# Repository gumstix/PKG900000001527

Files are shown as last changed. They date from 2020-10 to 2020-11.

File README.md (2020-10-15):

# Gumstix Raspberry Pi CM4 PoE Smart Camera
# PKG900000001527 

The **Gumstix Raspberry Pi CM4 PoE Smart Camera** carrier board combines Power over Ethernet and Google's Coral AI accelerator chip with the Raspberry Pi CM4 and Raspberry Pi Camera to deliver a fast and powerful image classification, object identification or behavioral inference computer with low latency and single-cable deployment.

__Features Include__:
* Google Coral G313 TPU
* Raspberry Pi Camera connector
* USB Gigabit Ethernet and power via Silvertel Ag9700
* Board to board connectors for the Raspberry Pi CM4

__Links:__
* [AutoDoc Datasheet][autodoc]
* [Specifications][spec]
* [Store Page][store]
* [Schematics and Layout][hardware]

[thumbnail]: about:blank
[autodoc]: PKG900000001527_AutoDoc.pdf
[spec]: PKG900000001527_SpecSheet.pdf
[store]: https://store.gumstix.com/cm4-poe-smart-camera/
[hardware]: hardware/hardware.md
[firmware]: firmware/firmware.md

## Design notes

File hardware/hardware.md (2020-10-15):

# Hardware

[Schematic PDF][pdf]
EAGLE [Schematic][sch] and [Layout][brd]

[pdf]: PKG900000001527.pdf
[brd]: PKG900000001527.brd
[sch]: PKG900000001527.sch

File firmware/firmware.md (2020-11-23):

# Firmware

__Custom Gumstix Ubuntu Server 20.04 images for Rasberry Pi CM4__:

* [Ubuntu Server 20.04](https://gumstix-ubuntu.s3-us-west-2.amazonaws.com/2020-10-18/raspberrypi-cm4/rosbuntu_cm4_i2.img.gz)
* Username: ubuntu
* Password: raspberry

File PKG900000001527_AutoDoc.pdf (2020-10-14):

# CM4 PoE Smart Camera

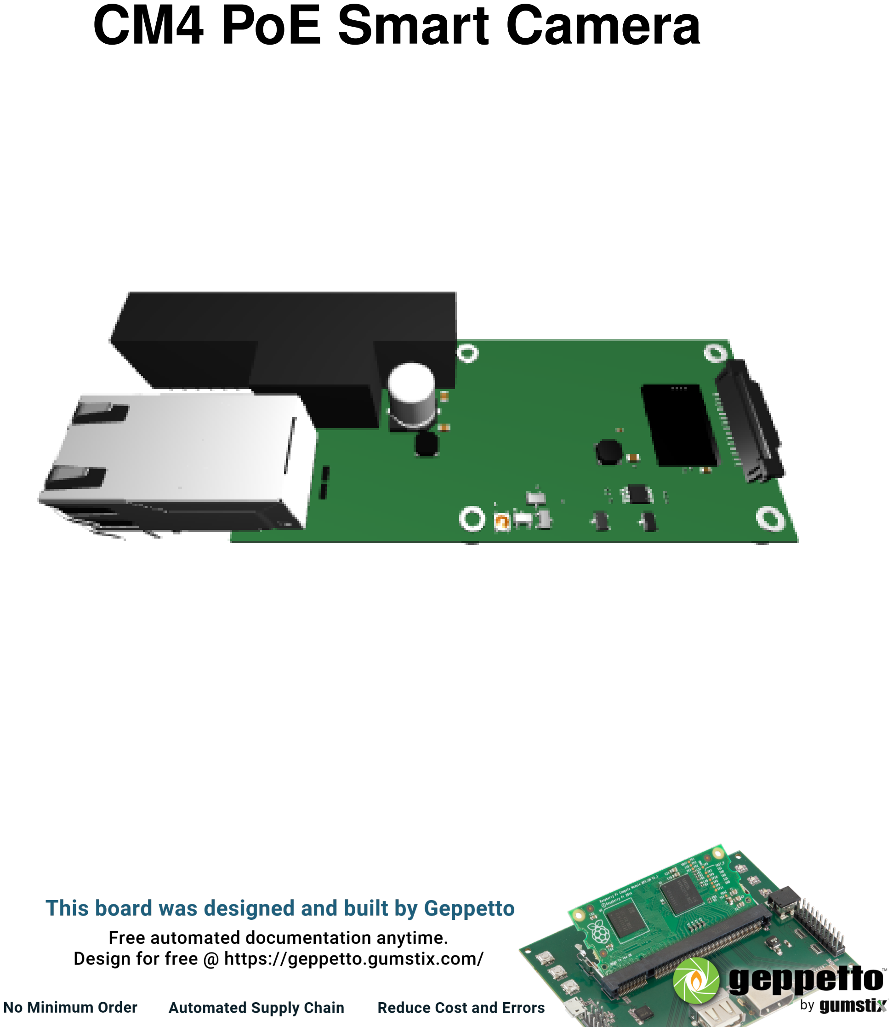
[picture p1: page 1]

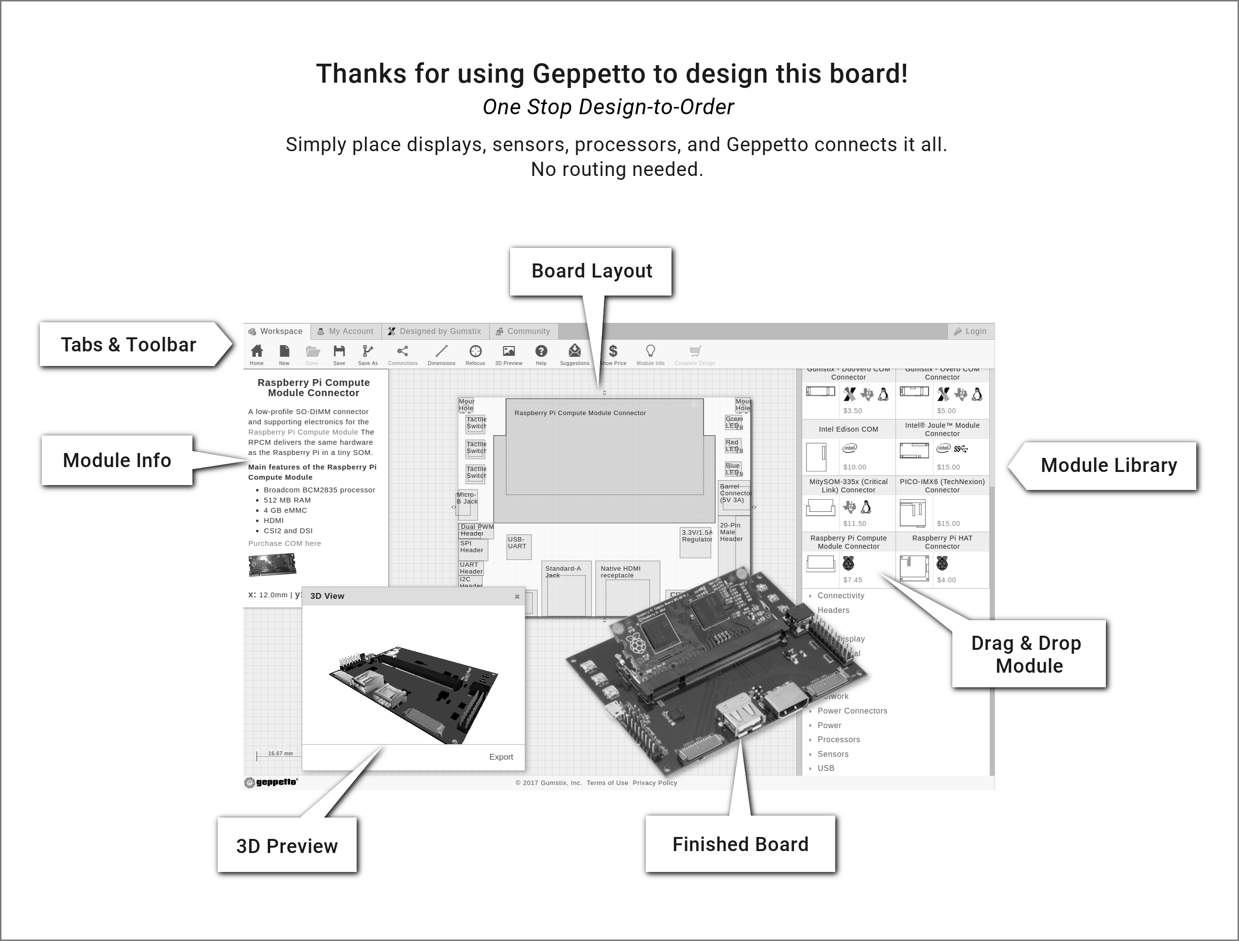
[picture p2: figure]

Gumstix, Inc. shall have no liability of any kind, express or implied, arising out of the use of the Information in this document, including direct, indirect, special or consequential damages.

Gumstix, Inc. may have patents, patent applications, trademarks, copyrights, trade secrets or other intellectual property rights pertaining to Gumstix products described in this document (collectively ”Gumstix Intellectual Property”).

Except as expressly provided in any written license or agreement from Gumstix, Inc., this document and the information contained therein does not create any license to Gumstix’s Intellectual Property.

The Information contained herein is subject to change without notice. Revisions may be issued regarding changes and/or additions.

Copyright

c 2020, Gumstix, Inc. All rights reserved.

## Board Description

Uses Raspberry Pi CM4 Connector (Flip-side) as its COM/processor.

Functional modules include:
Gigabit via USB with Silvertel Ag9700 PoE
Google Coral G313-06329-00 Accelerator Raspberry Pi Vertical Camera Connector

## Board Dimensions

4cm x 9cm

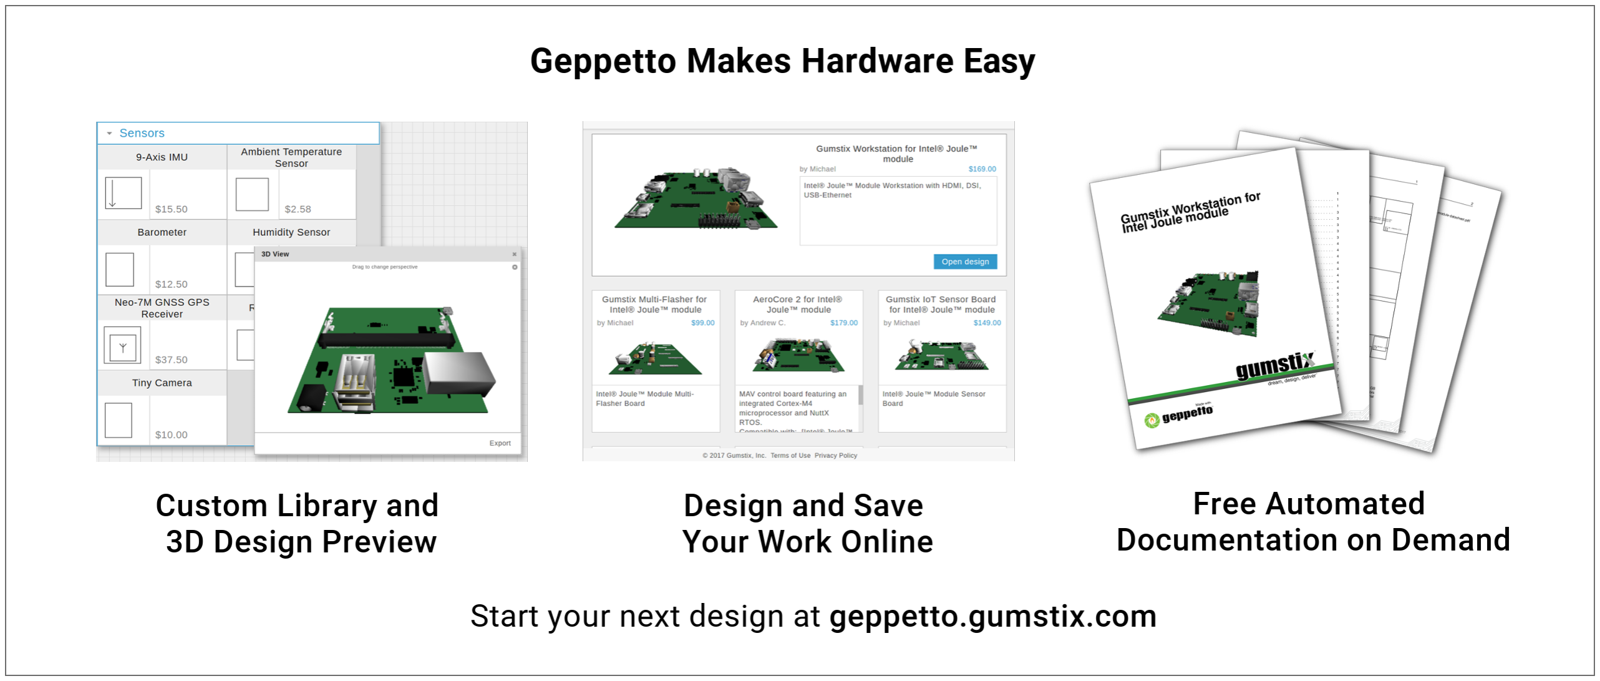
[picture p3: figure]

i

## Contents

1 Modules on Board | 1
2 Module Connections Graph | 5
3 Module Power Graph | 6

ii

CM4 PoE Smart Camera | 1

## 1 Modules on Board

1

1000BaseT ->ETHERNET (5)

GPIO_CAMERA ->ENABLE (4)

CAM1 ->CSI (4)

PCIE CLKREQ ->PCIE nCLKREQ (2)

PCIE ->PCIe (2)

AUDIO ->I2S (7)

2

3

3.3V ->3.3V (5)

3.3V ->3.3V (4)

3.3V ->VIN (7)

4

5

5.0V ->VIN (3)

6

VCC_5.0 ->5.0V (1)

VCC_3.3 ->3.3V (2)

7

Revised September 23, 2020

### 1.1 COM Connectors

### 1.1.1 Raspberry Pi CM4 Connector (Flip-side) (v4) (1)

The Raspberry Pi Compute Module 4 (RPCM4) module contains two connectors to interface with the RPCM4 device. The RPCM4 COM connector is ONLY compatible with the RPCM4. The module is placed on the flip-side of the board.

Technical details for the RPCM modules can be found at:

https://www.raspberrypi.org/documentation/hardware/computemodule/datasheet.md

It requires:

- 5.0V from Dummy Power Provider (6)

The Geppetto Pi Compute 4 connector provides the following outputs:

- 1000BaseT to Gigabit with Silvertel Ag9700 PoE (5)
- GPIO CAMERA to Raspberry Pi Vertical Camera Connector (4)
- CAM1 to Raspberry Pi Vertical Camera Connector (4)
- PCIE CLKREQ to Google Coral G313-06329-00 Accelerator (2)
- PCIE to Google Coral G313-06329-00 Accelerator (2)
- AUDIO to Knowles SPH0645LM4H-B Microphone (7)

### 1.2 Sensors

### 1.2.1 Google Coral G313-06329-00 Accelerator (v2) (2)

The Google Coral Accelerator Module is a multi-chip module (MCM) that includes the Edge TPU and its own power control. The Edge TPU is a small ASIC designed by Google that accelerates Tensor Flow Lite models using little power: it’s capable of performing 4 trillion operations per second (4 TOPS), using 2 watts of powerthat’s 2 TOPS per watt. For example, it can execute state-of-the-art mobile vision models such as MobileNet v2 at almost 400 frames per second, in a power efficient manner. This on-device ML processing reduces latency, increases data privacy, and removes the need for a constant internet connection. The module provides either of the host interface i.e. PCIe Gen2 x 1 or USB2.0.

The datasheet for the G313-06329-00 module is available at:

https://coral.ai/static/files/Coral-Accelerator-Module-datasheet.pdf

The module connects to the following buses:

- PCIE nCLKREQ to PCIE CLKREQ on Raspberry Pi CM4 Connector (Flip-side) (1)
- VLOGIC PCIE CTRL to VLOGIC on Raspberry Pi CM4 Connector (Flip-side) (1)
- PCIe to PCIE on Raspberry Pi CM4 Connector (Flip-side) (1)

•

### 1.3 Power

1.3.1 3.3V/1.5A Regulator (v21) (3)

This DC to DC step down regulator provides a 3.3V DC output at 1.5A needed by certain components on this board. It is capable of accepting an input voltage between 3.1 to 16V DC and output is controlled by the TI TPS6211 buck regulator.
It recieves VIN from Gigabit with Silvertel Ag9700 PoE (5).

The datasheet for the TPS6211 regulator is available at:

http://www.ti.com/lit/ds/symlink/tps62110.pdf

This regulator provides 3.3V to:

- Gigabit with Silvertel Ag9700 PoE (5)
- Raspberry Pi Vertical Camera Connector (4)
- Knowles SPH0645LM4H-B Microphone (7)

### 1.3.2 Dummy Power Provider (v5) (6)

This module does nothing except as a means to satisfy power requirements in Geppetto web. THIS DOES NOT ACTUALLY PROVIDE POWER.

### 1.4 Connectors (Signal)

### 1.4.1 Raspberry Pi Vertical Camera Connector (v6) (4)

The Raspberry Pi Vertical camera connector module is a 15-pin ribbon connector that exposes a 2-lane MIPI camera system to an external high-resolution camera module.

The CSI port is connected to CAM1 on Raspberry Pi CM4 Connector (Flip-side) (1).

I2C communication is connected to on .

ENABLE input provided by GPIO CAMERA on Raspberry Pi CM4 Connector (Flip-side) (1).

### 1.5 Network and Wireless

### 1.5.1 Gigabit with Silvertel Ag9700 PoE (v1) (5)

This module provides a gigabit ethernet interface connected to Raspberry Pi CM4 Connector (Flip-side) (1). This Power over Ethernet module provides 5V to the following modules:

- 3.3V/1.5A Regulator (3)

### 1.6 Audio

### 1.6.1 Knowles SPH0645LM4H-B Microphone (v1) (7)

The SPH0645LM4H-B is a miniature, low power, bottom port microphone with an I2S digital output. The solution consists of a proven high performance SiSonic acoustic sensor, a serial Analog to Digital converter, and an interface to condition the signal into an industry standard 24-bit I2S format. The I2S interface simplifies the integration in the system and allow direct interconnect to digital processors, application processors and microcontrollers saving the need of an external audio codec, the SPH0645LM4H-B is perfectly suitable for portable applications where size and power consumption are
a constraint. The operating supply voltage range of the microphone is between 1.62V and 3.6V.

The datasheet for the SPH0645LM4H-B is available at: https://www.knowles.com/docs/default-source/model-downloads/sph0645lm4h-b-datasheet-rev-c.pdf (https://www.knowles.com/docs/default-source/model-downloads/sph0645lm4h-b-datasheet-rev-c.pdf)

The SPH0645LM4H-B receives:

- I2S from AUDIO on Raspberry Pi CM4 Connector (Flip-side) (1)
- VIN from 3.3V on 3.3V/1.5A Regulator (3)

## 2 Module Connections Graph

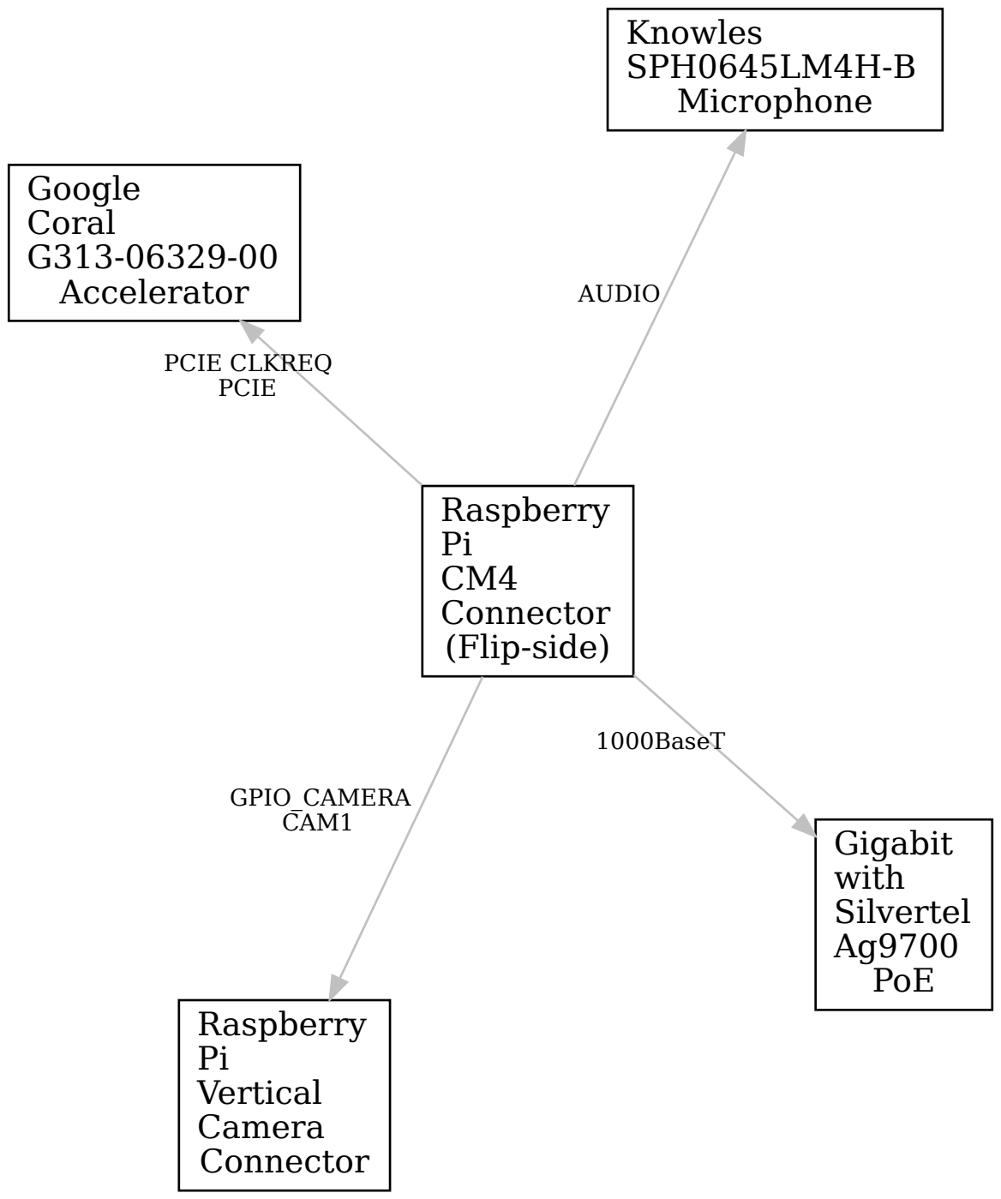
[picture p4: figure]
Raspberry Pi CM4 Connector (Flip-side); Gigabit with Silvertel Ag9700 PoE; 1000BaseT; Raspberry Pi Vertical Camera Connector; GPIO_CAMERA CAM1; Google Coral G313-06329-00 Accelerator; PCIE CLKREQ PCIE; Knowles SPH0645LM4H-B Microphone; AUDIO

Figure 1: excludes power modules

## 3 Module Power Graph

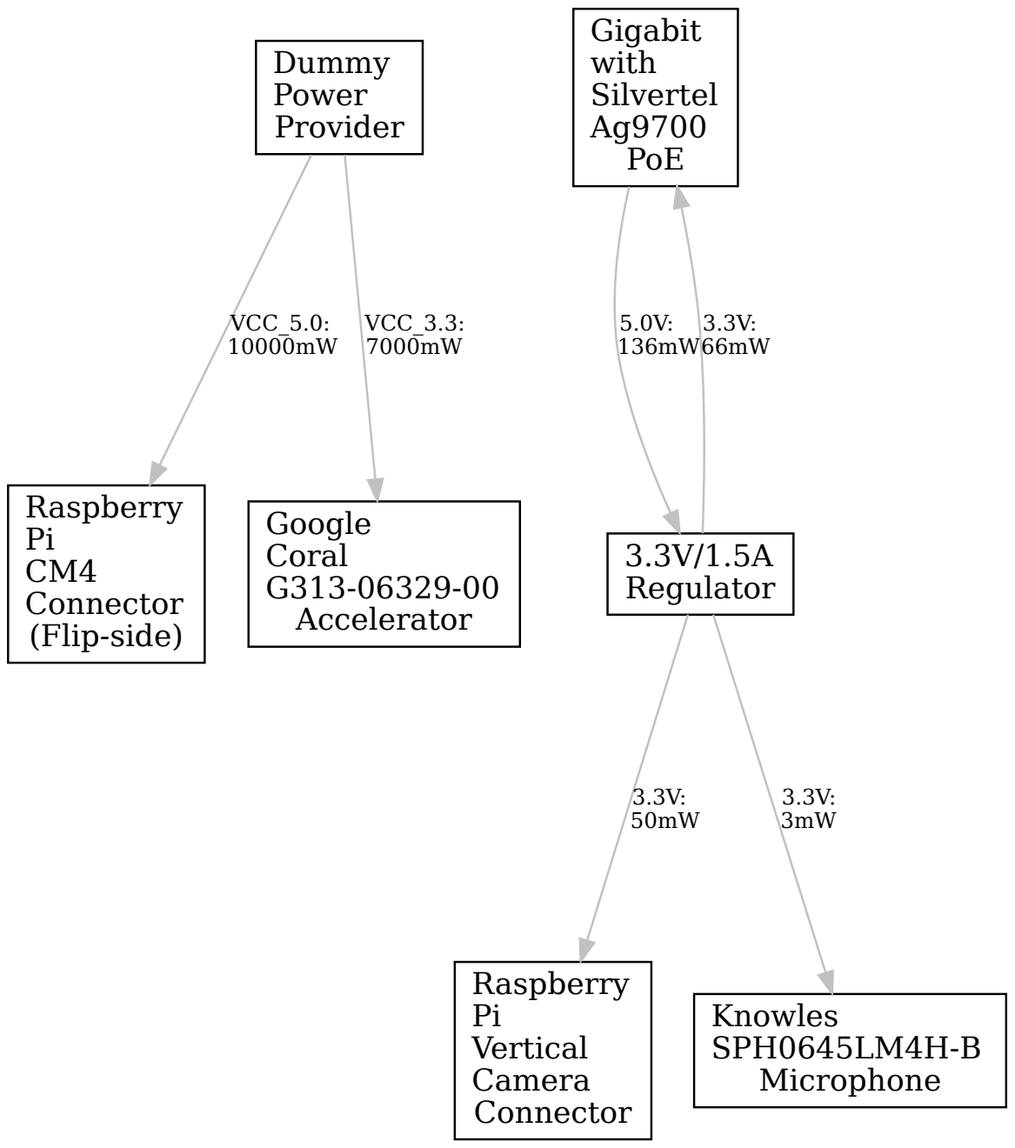
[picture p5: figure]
Dummy Power Provider; Raspberry Pi CM4 Connector (Flip-side); VCC_5.0: 10000mW; Google Coral G313-06329-00 Accelerator; VCC_3.3: 7000mW; Gigabit with Silvertel Ag9700 PoE; 3.3V/1.5A Regulator; Raspberry Pi Vertical Camera Connector; Knowles SPH0645LM4H-B Microphone

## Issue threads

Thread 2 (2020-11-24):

Expose higher voltage output from the PoE

hauleth, 2020-11-24:
It would be handy for the same reason as in #1 where magnetic locks use 12V and having everything powered by single PoE connection would be really handy for such projects.

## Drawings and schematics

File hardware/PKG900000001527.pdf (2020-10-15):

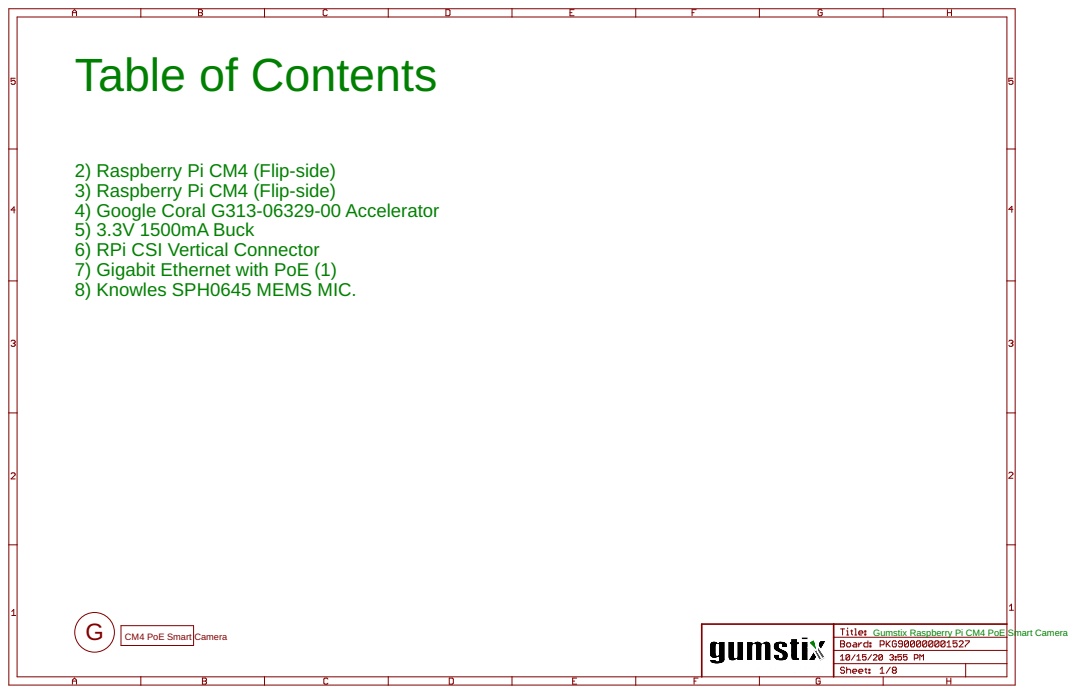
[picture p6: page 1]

2) Raspberry Pi CM4 (Flip-side)
3) Raspberry Pi CM4 (Flip-side)
4) Google Coral G313-06329-00 Accelerator
5) 3.3V 1500mA Buck
6) RPi CSI Vertical Connector
7) Gigabit Ethernet with PoE (1)
8) Knowles SPH0645 MEMS MIC.

Gumstix Raspberry Pi CM4 PoE Smart Camera

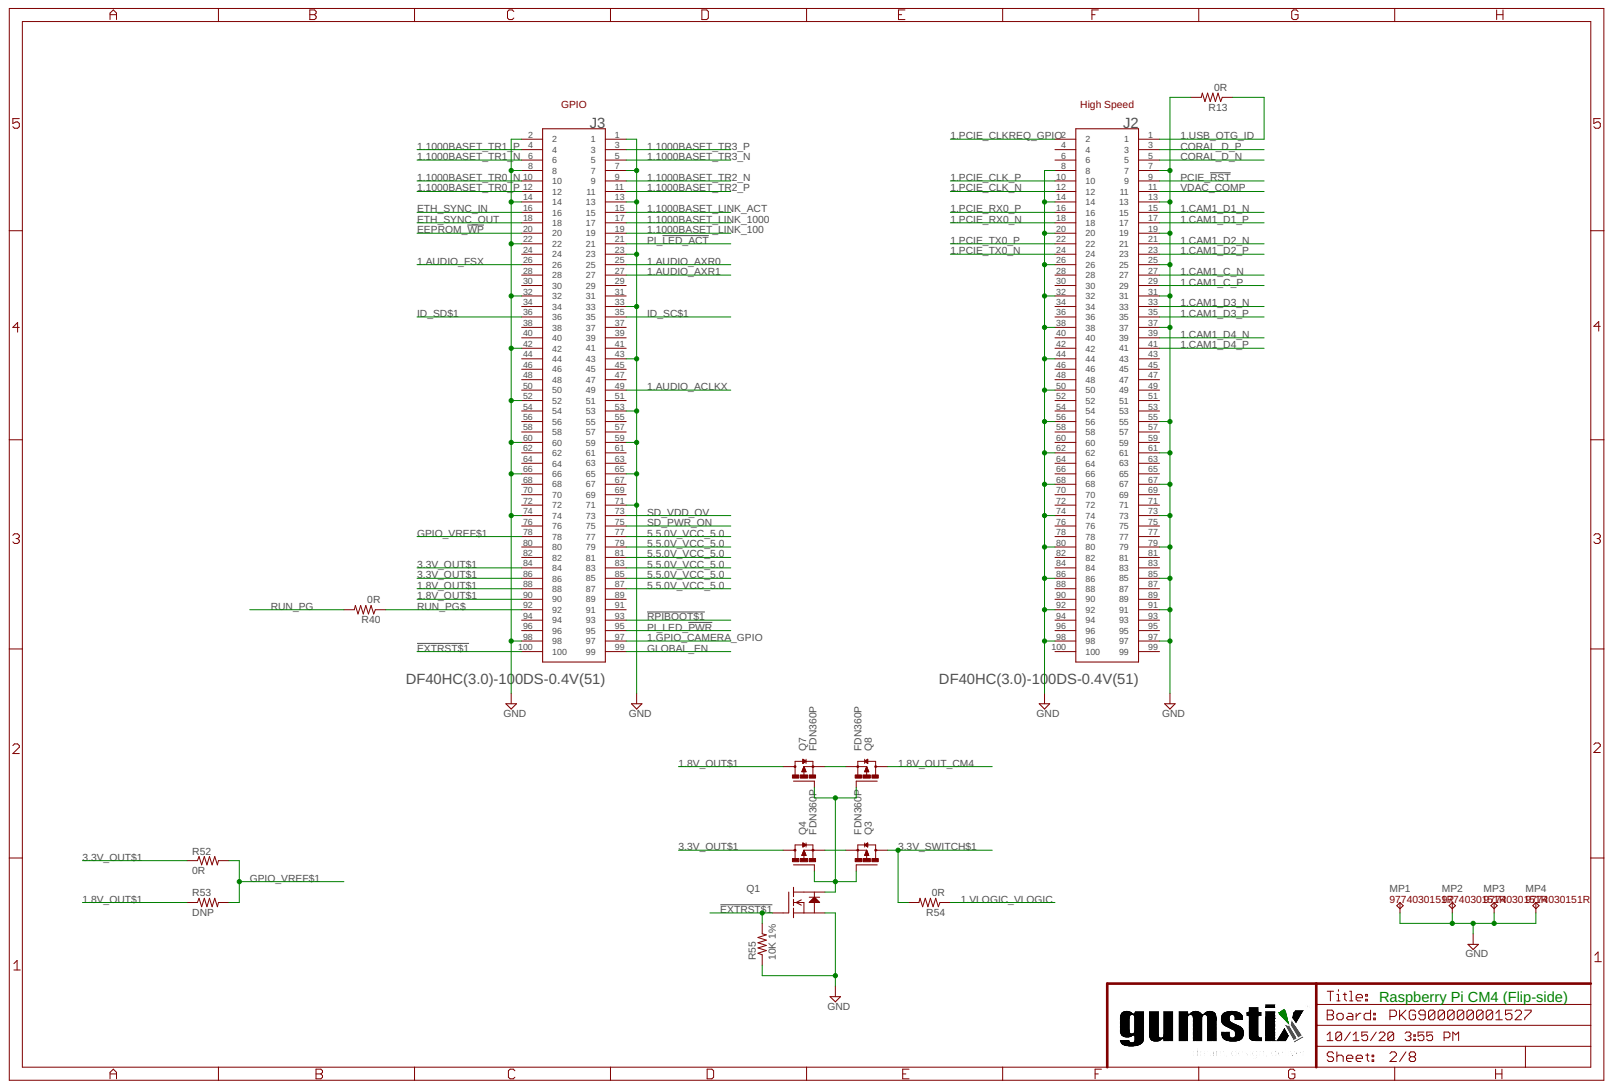
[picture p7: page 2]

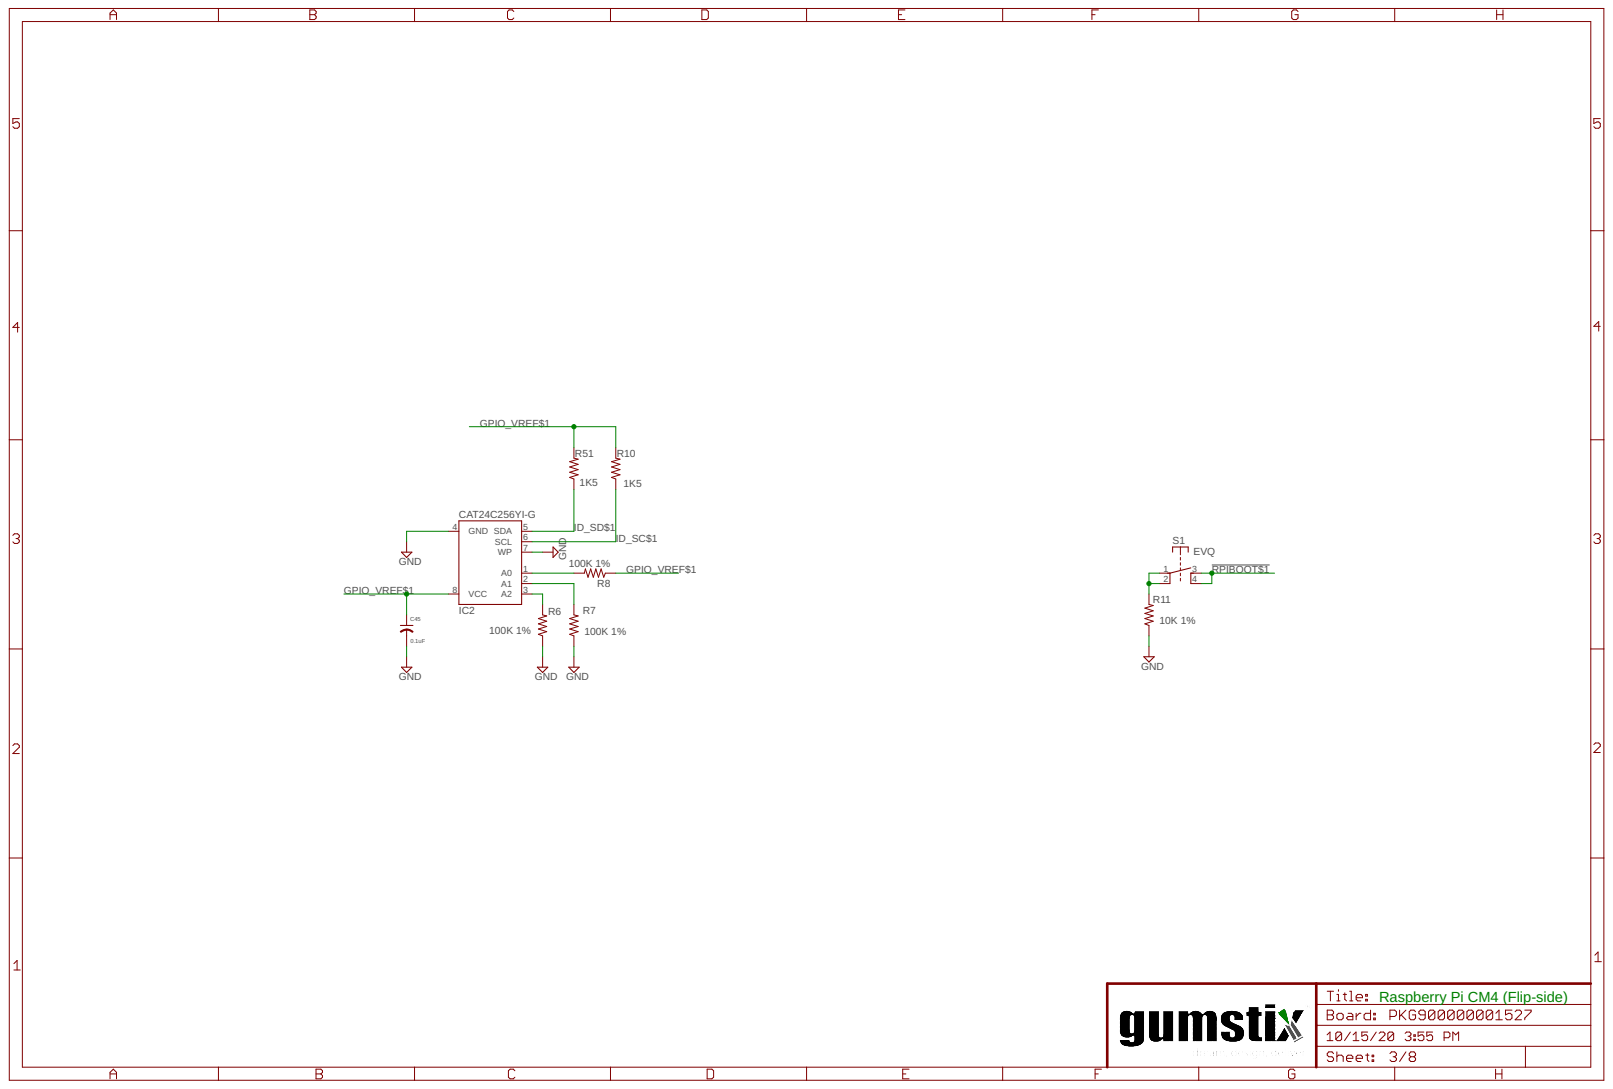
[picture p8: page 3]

Raspberry Pi CM4 (Flip-side)

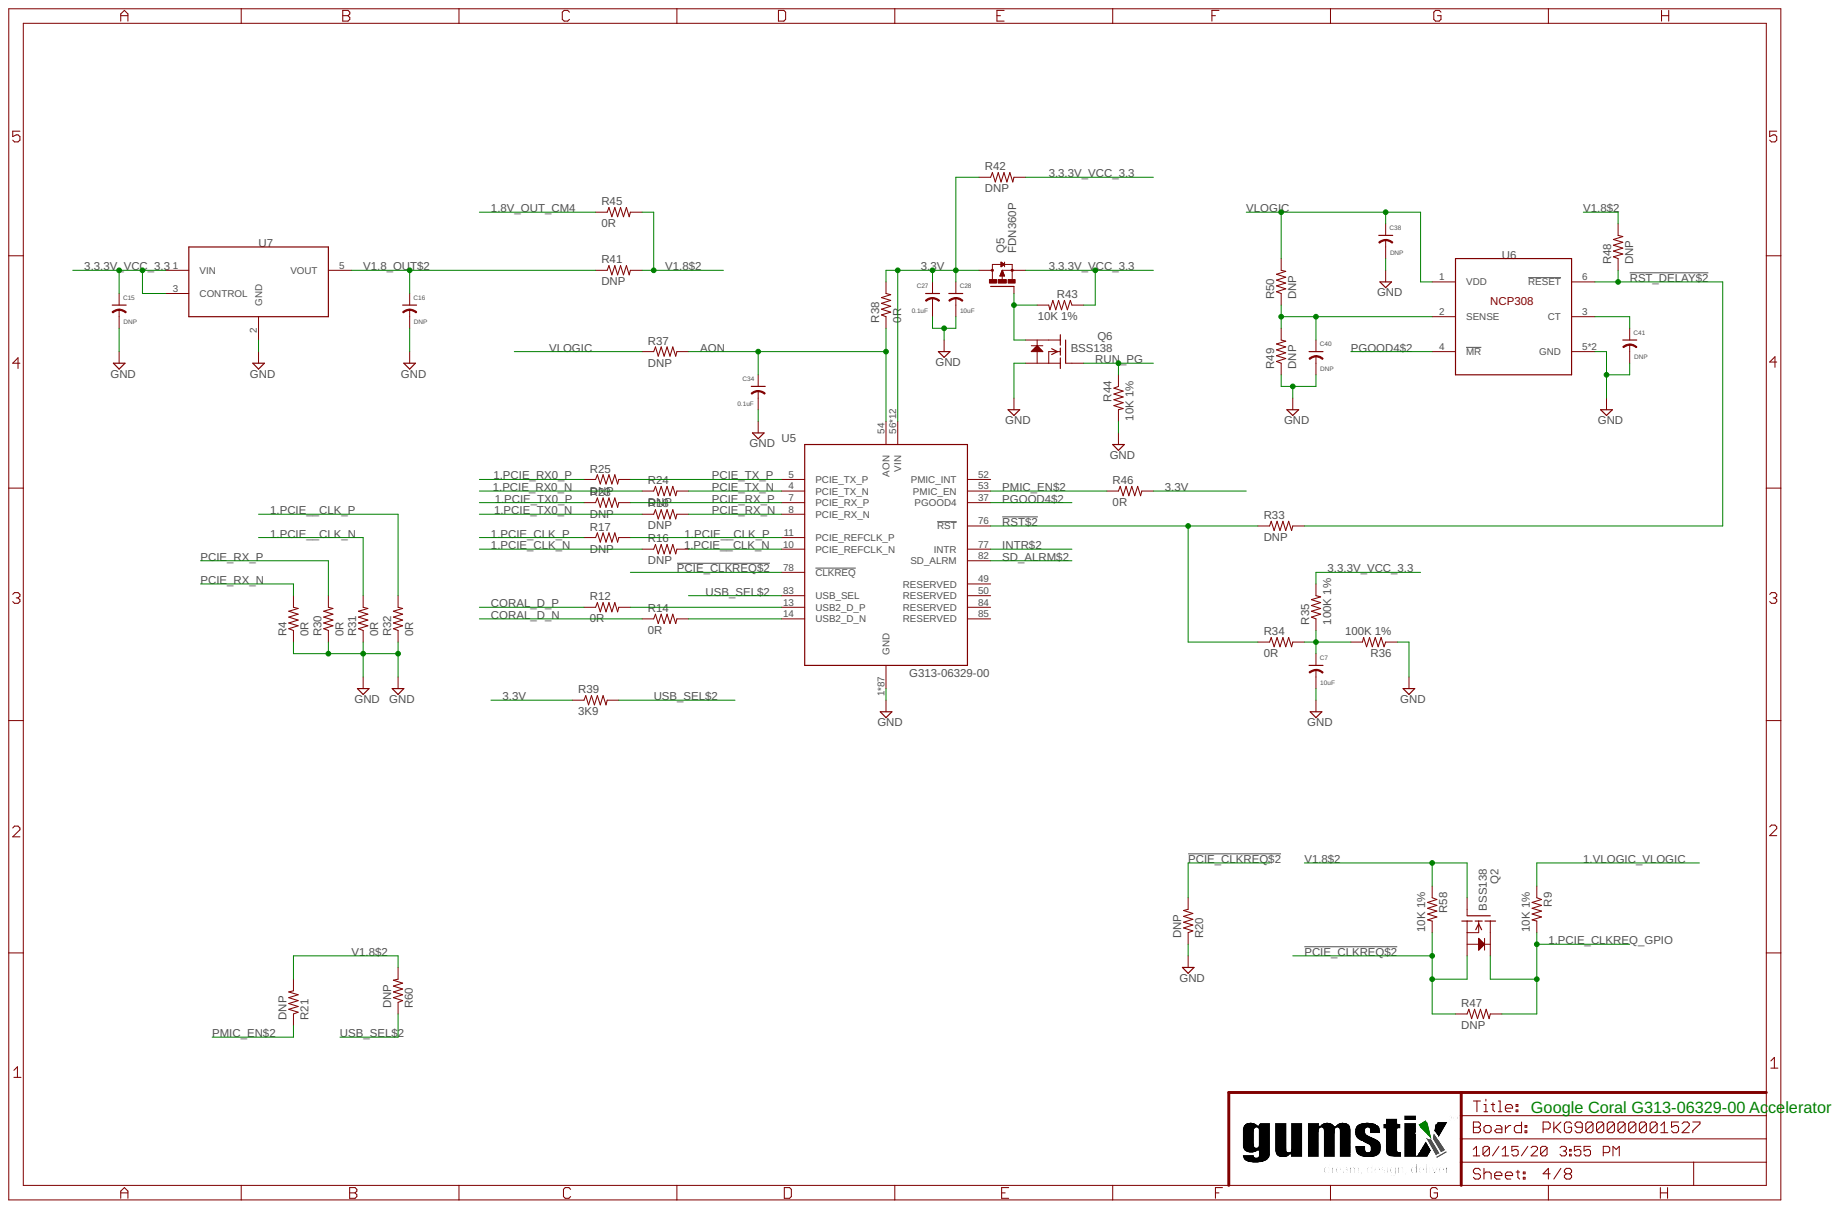
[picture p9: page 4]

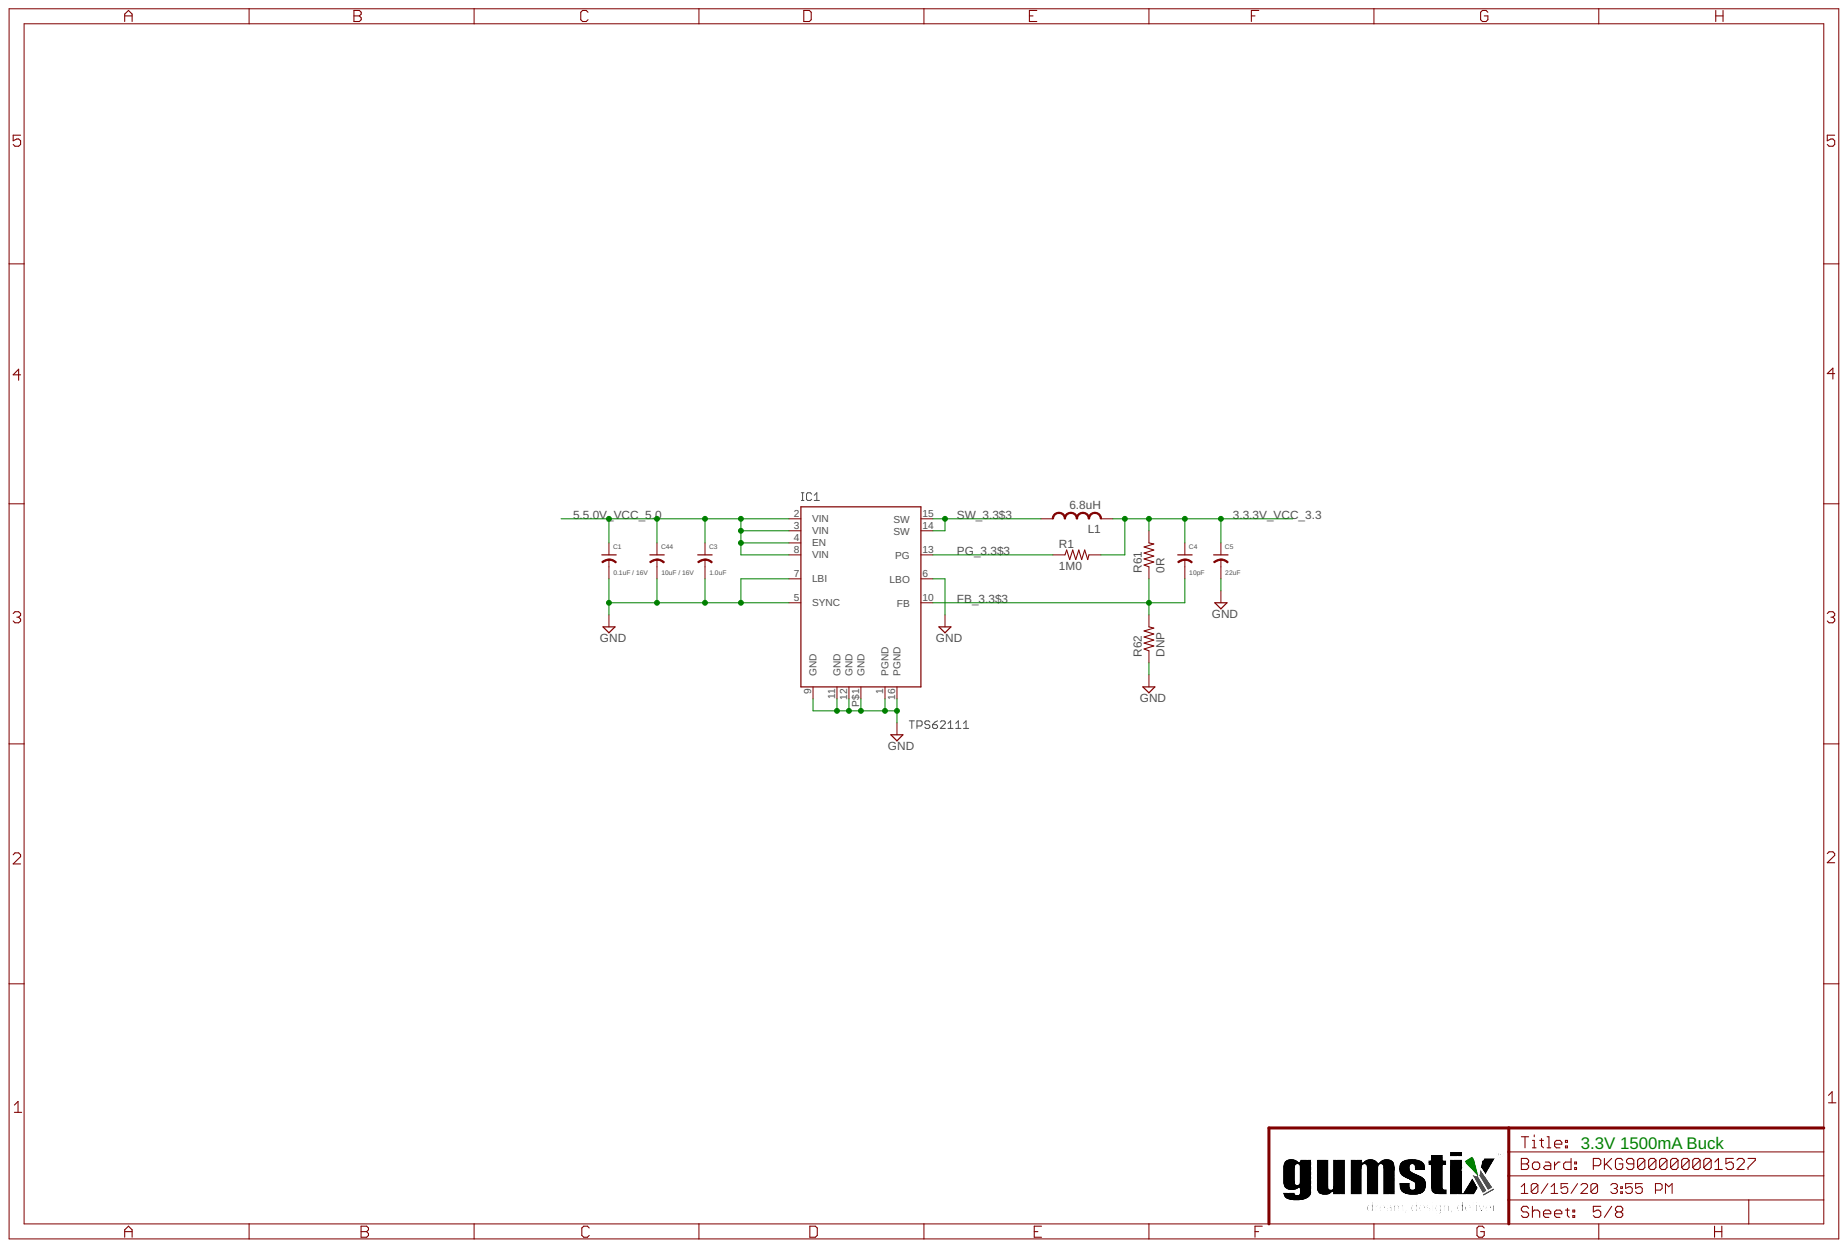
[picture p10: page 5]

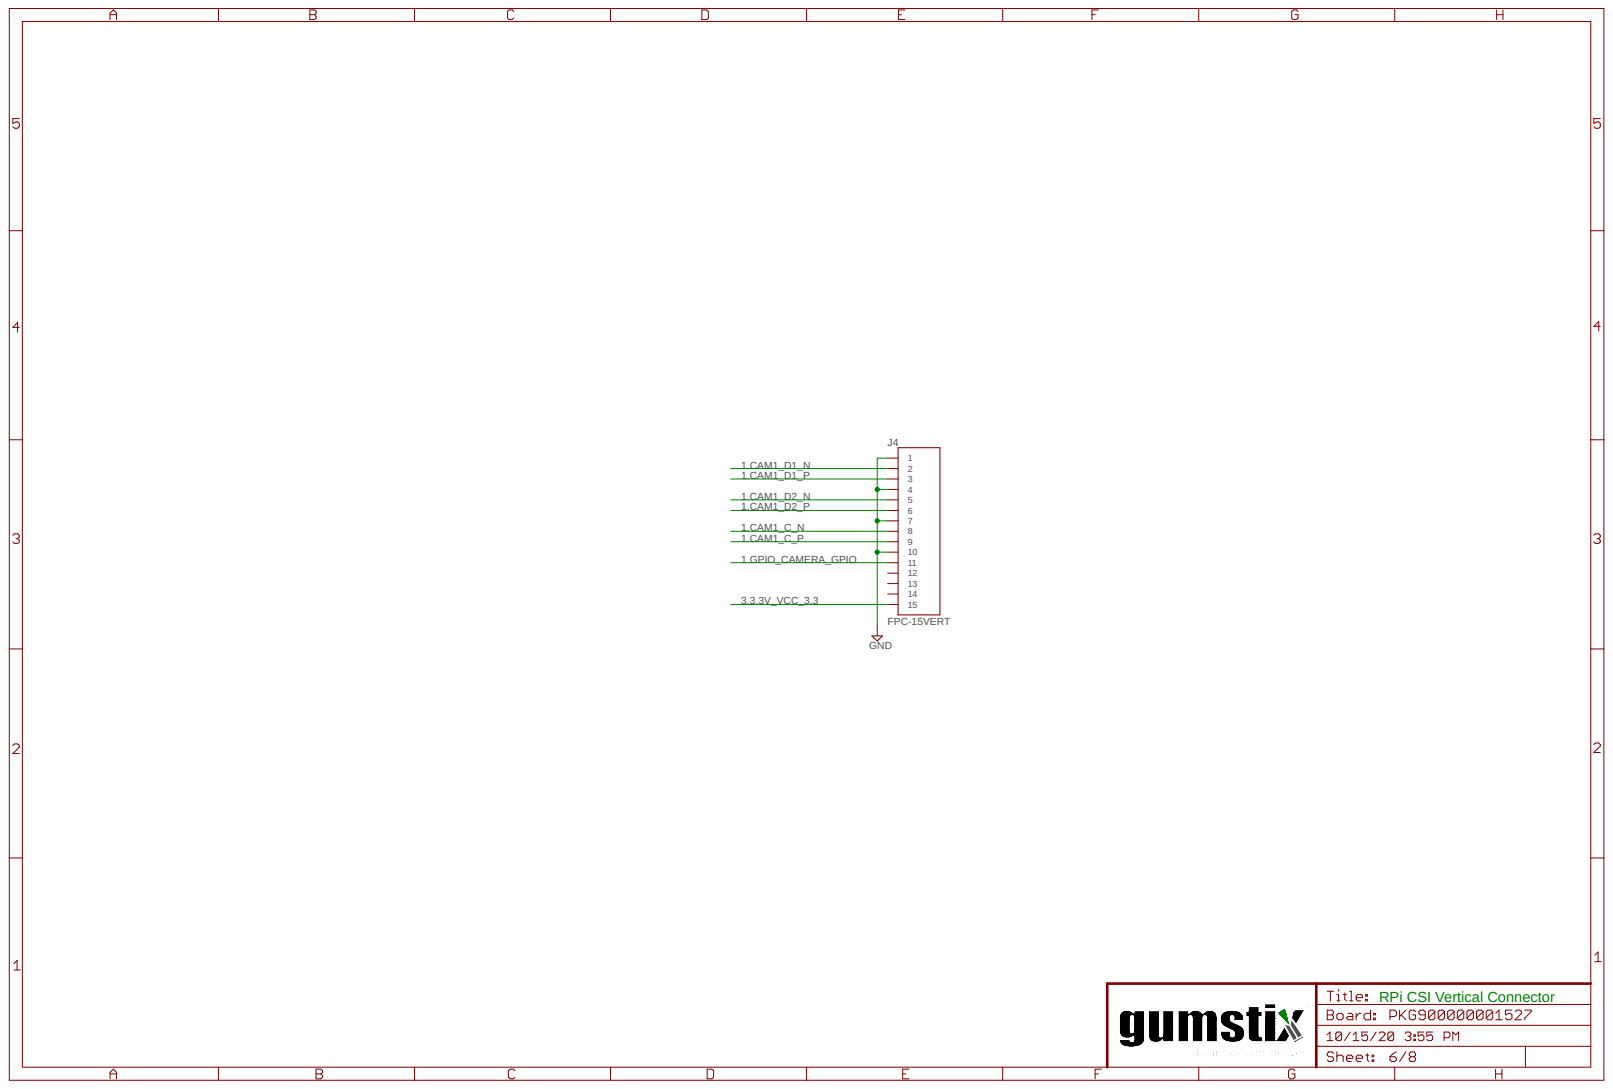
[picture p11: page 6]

RPi CSI Vertical Connector

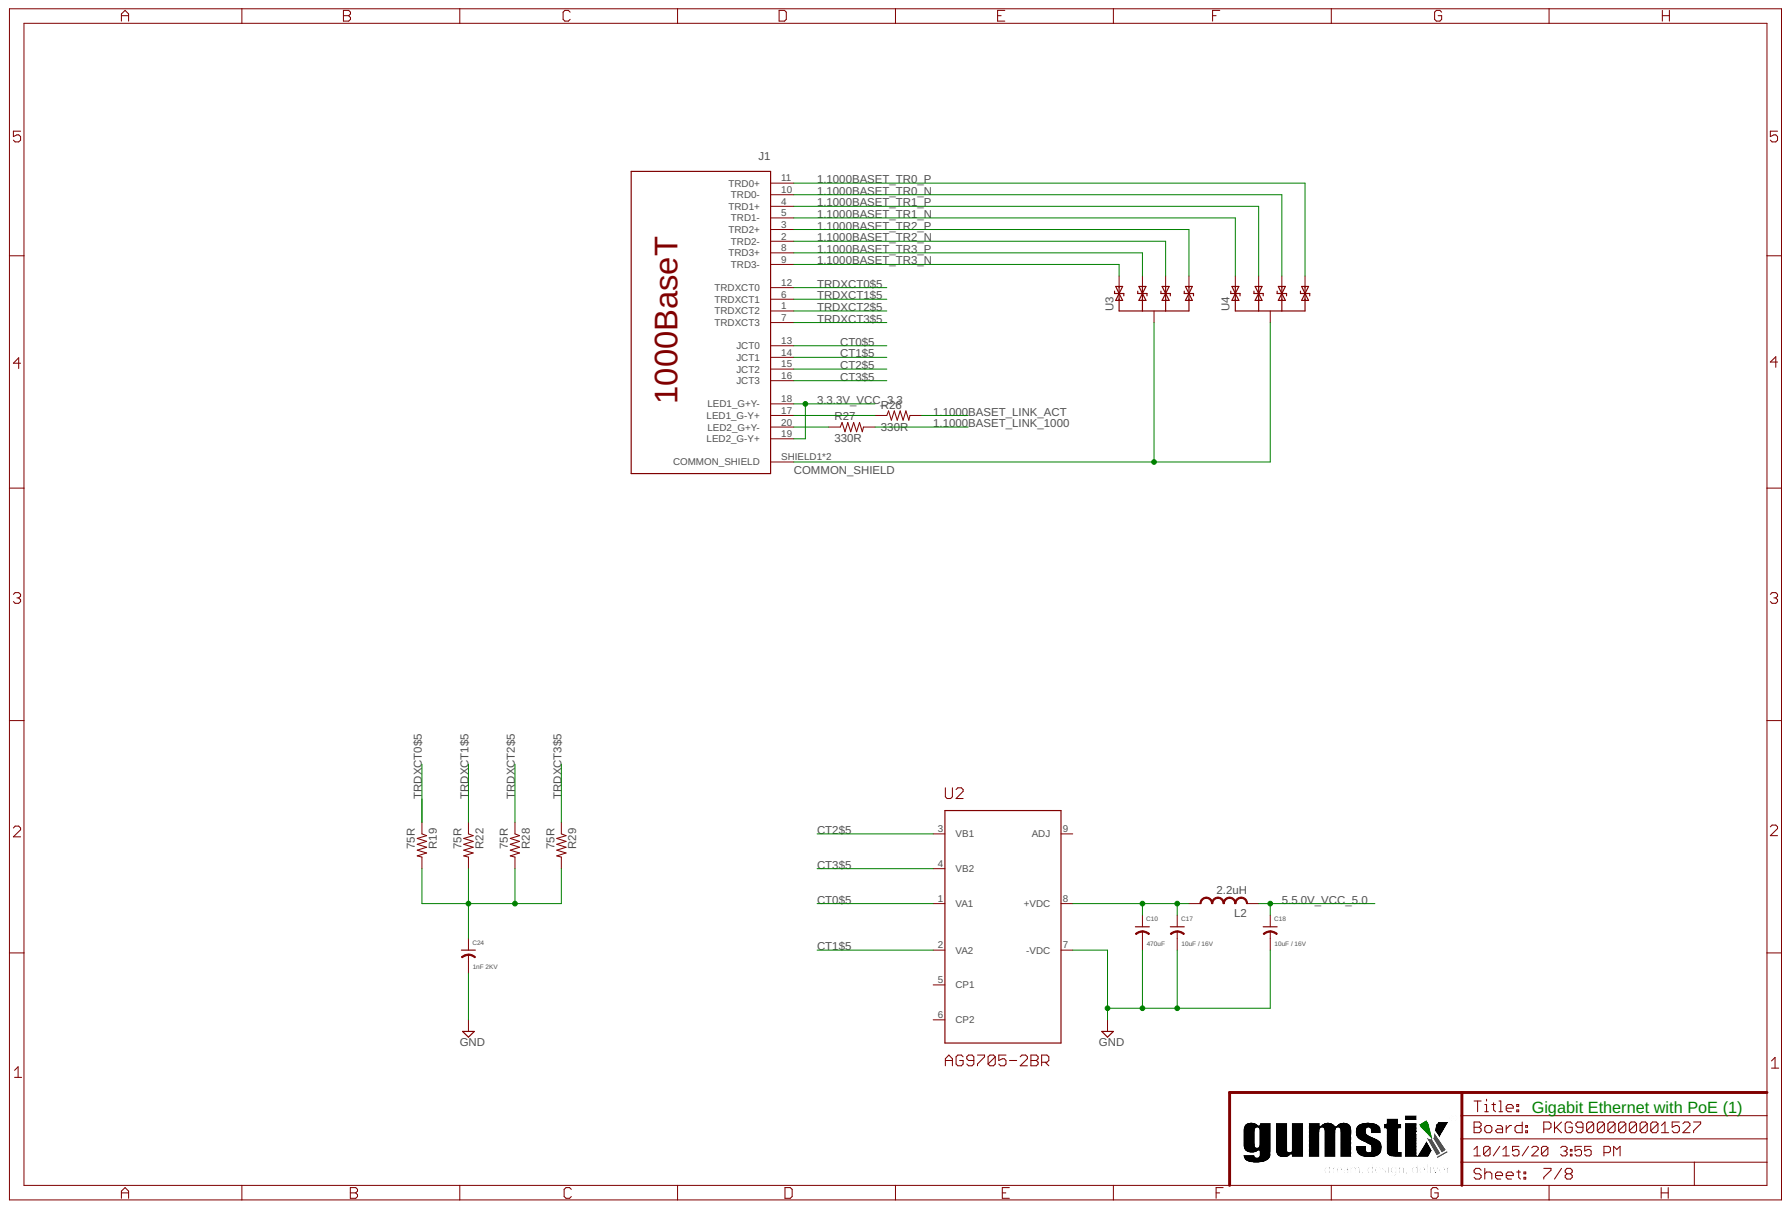
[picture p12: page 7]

Gigabit Ethernet with PoE (1)

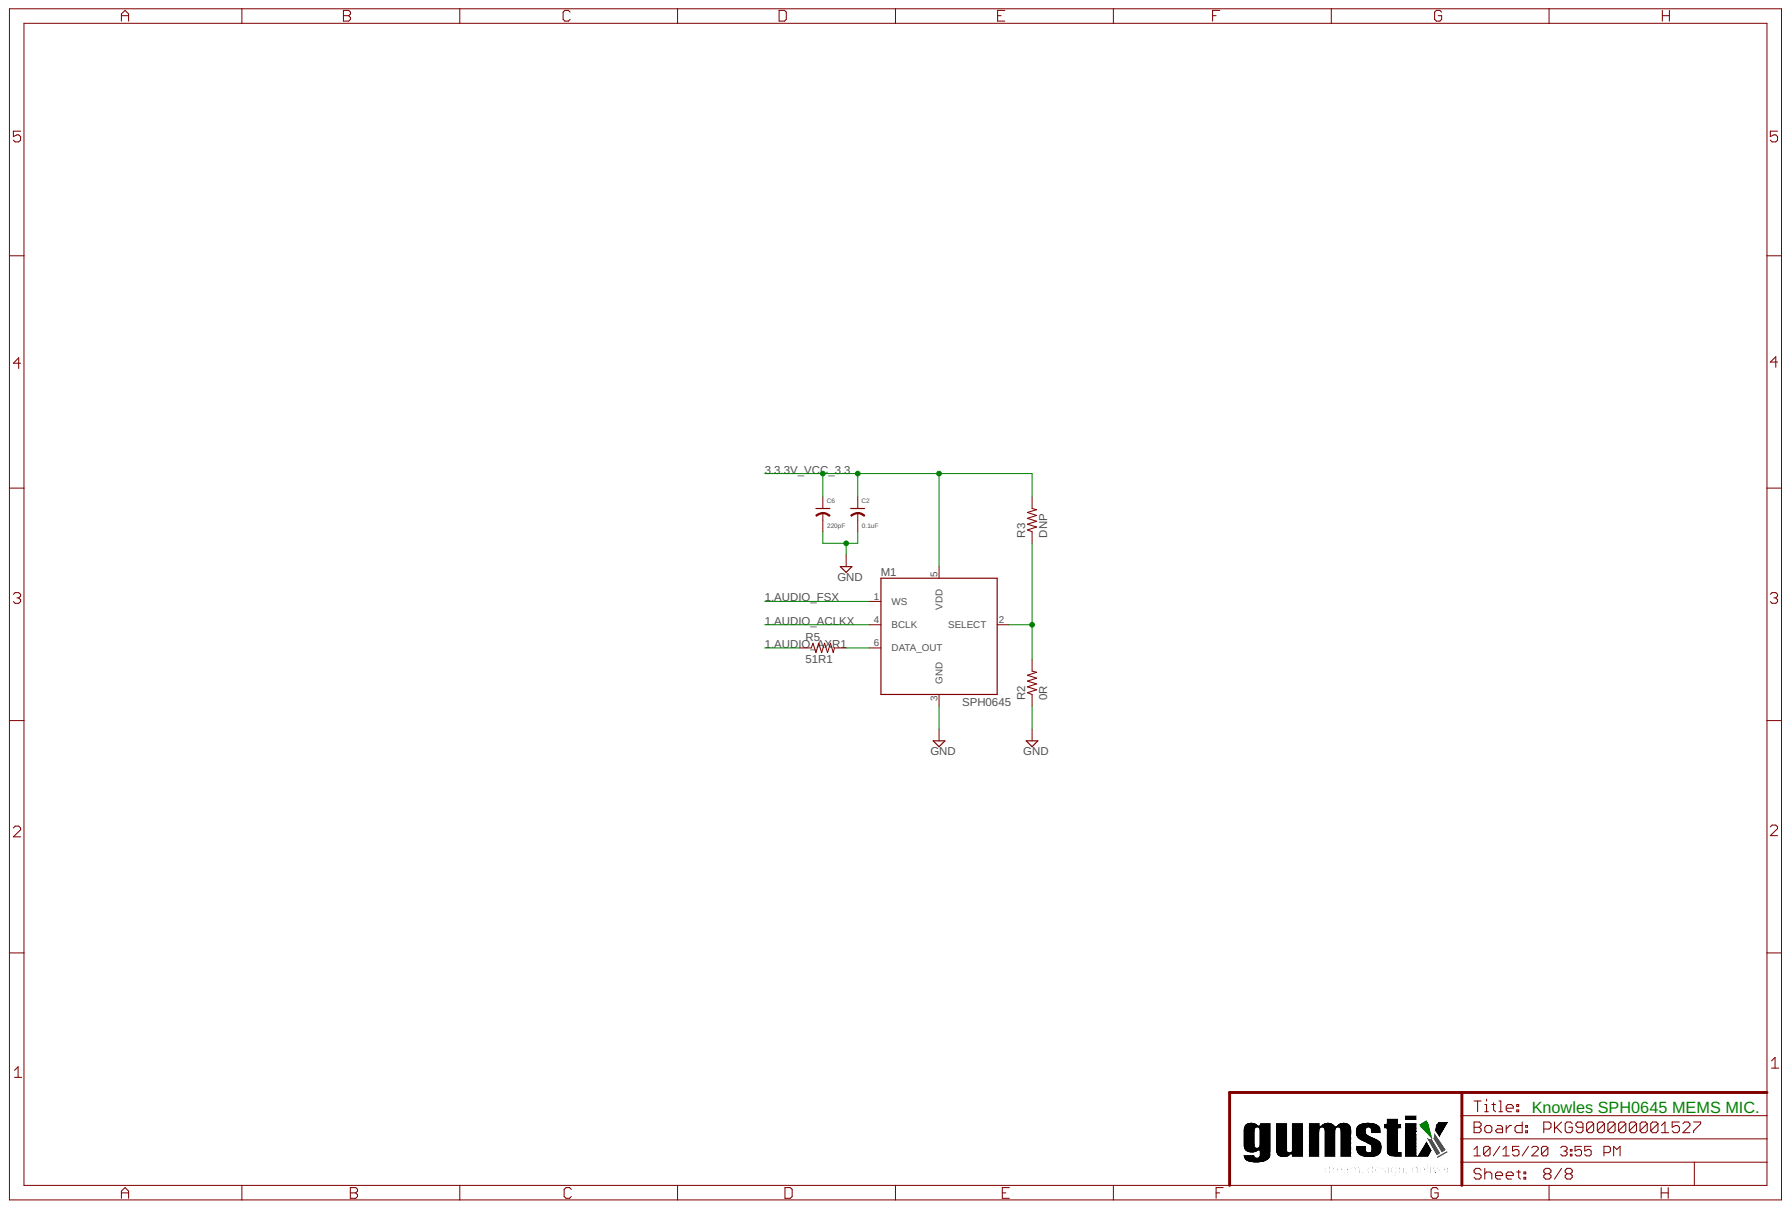
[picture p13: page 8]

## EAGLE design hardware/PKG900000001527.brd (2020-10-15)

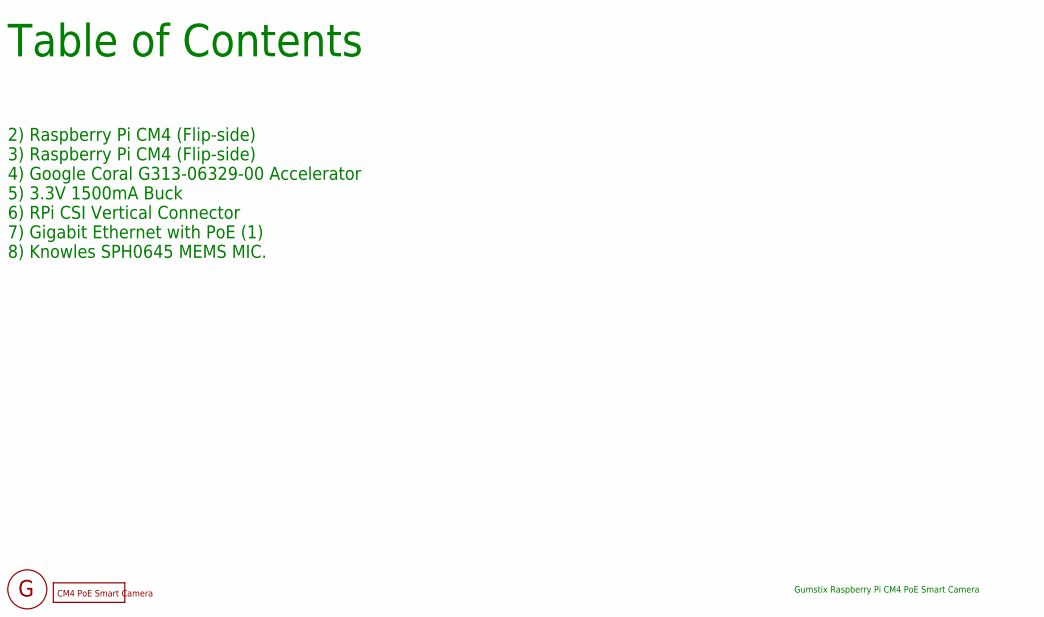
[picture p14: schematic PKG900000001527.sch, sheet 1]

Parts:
FD1, FD2, FD3, FD4, FD5, FD6: DNP; FIDUCIAL
U$2: DNP; GEPPETTO_LABEL
U$3: DNP; GEPPETTO_LOGO_SILK10

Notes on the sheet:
Table of Contents
Gumstix Raspberry Pi CM4 PoE Smart Camera
2) Raspberry Pi CM4 (Flip-side)
3) Raspberry Pi CM4 (Flip-side)
4) Google Coral G313-06329-00 Accelerator
5) 3.3V 1500mA Buck
6) RPi CSI Vertical Connector
7) Gigabit Ethernet with PoE (1)
8) Knowles SPH0645 MEMS MIC.

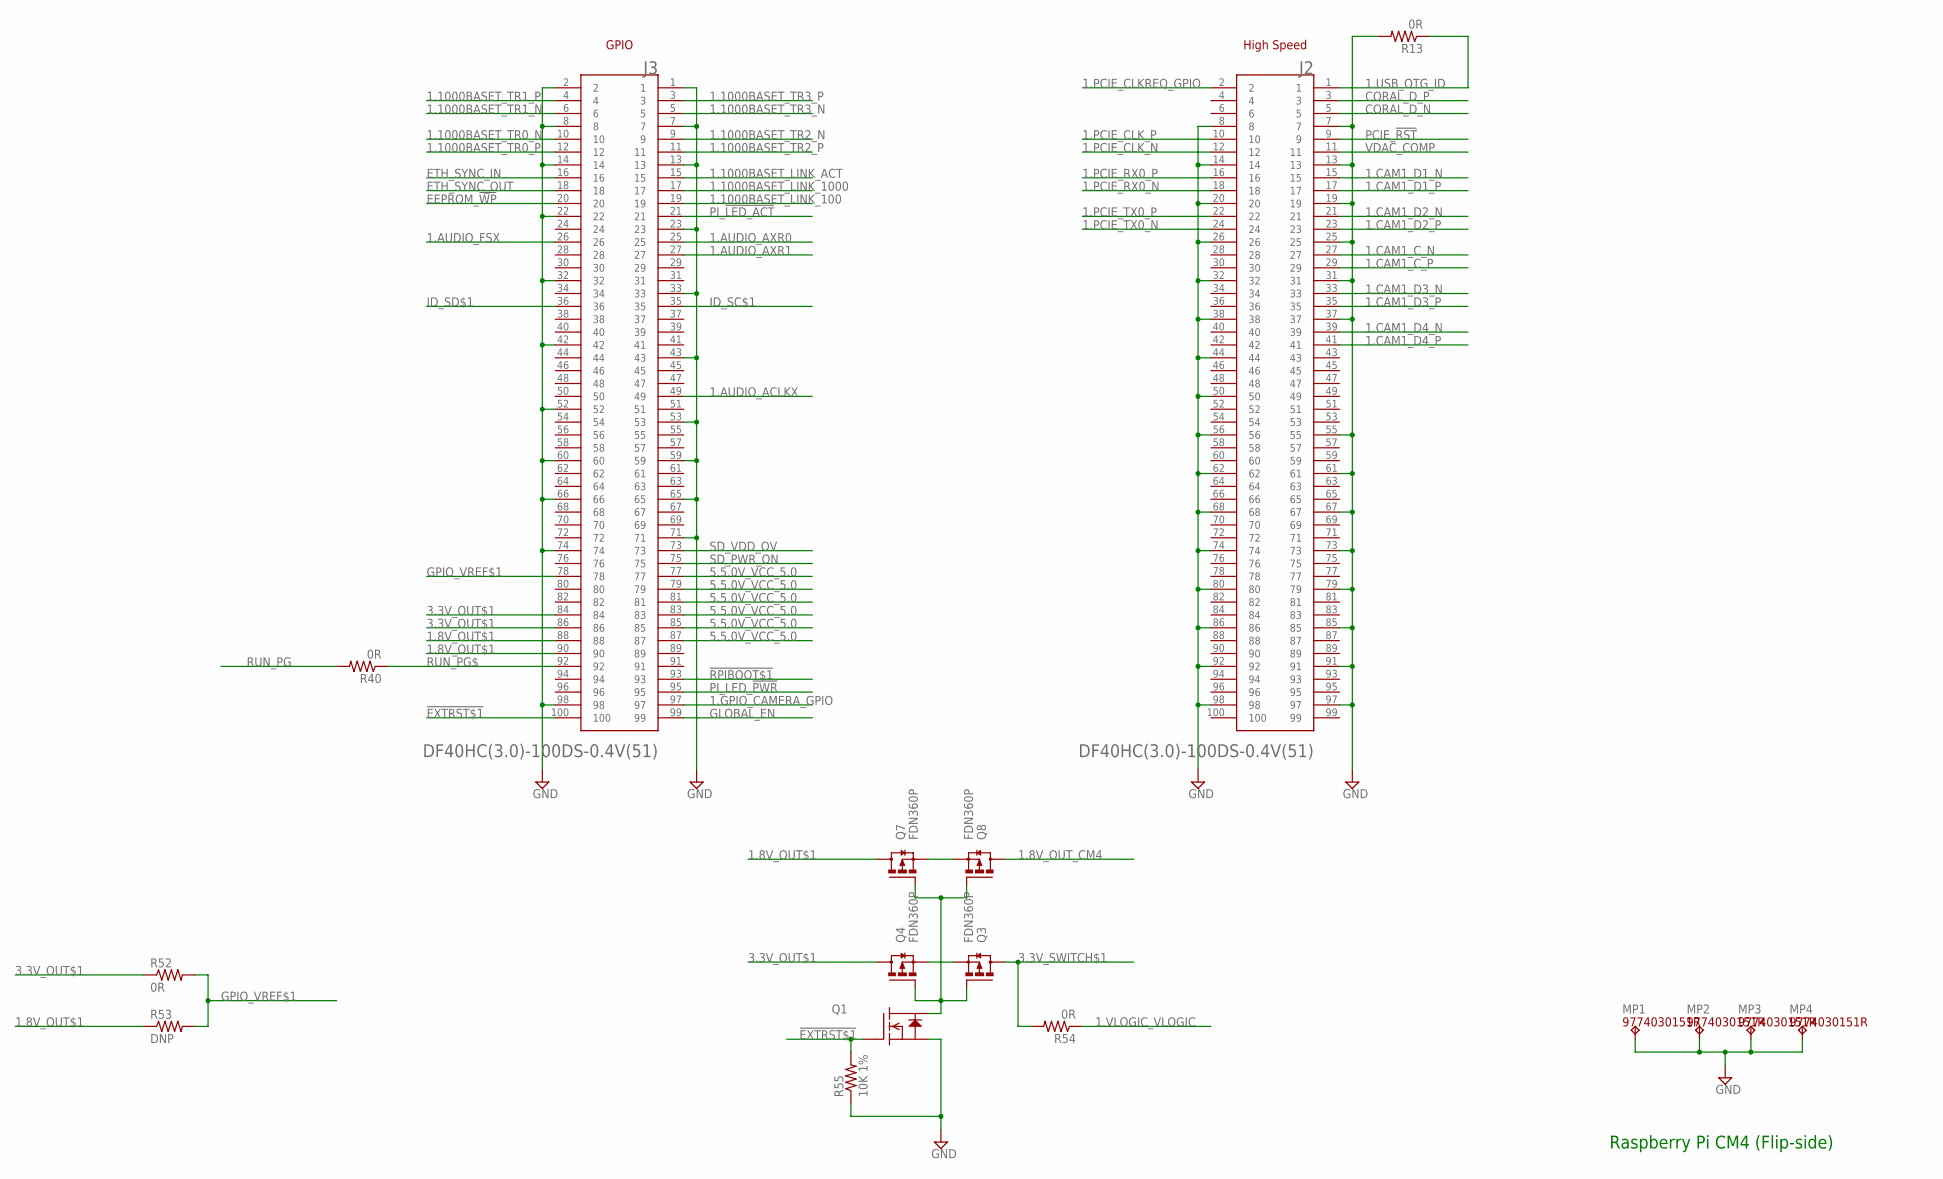
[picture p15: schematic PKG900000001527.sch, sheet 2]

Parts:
J2, J3: DF40HC(3.0)-100DS-0.4V(51); HRS_DF40C-100DS-0.4V(51)
MP1, MP2, MP3, MP4: 9774030151R; WA-SMSI_9774___151
Q1: BSS138; SOT23
Q3, Q4, Q7, Q8: FDN360P; SOT23
R13, R40, R52, R54: 0R; 0201
R53: DNP; 0201
R55: 10K 1%; 0201

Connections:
1.8V_OUT$1: J3.88, J3.90, Q7.3 (D), R53.1
1.8V_OUT_CM4: Q8.3 (D); also elsewhere on the board
1.1000BASET_LINK_100: J3.19
1.1000BASET_LINK_1000: J3.17; also elsewhere on the board
1.1000BASET_LINK_ACT: J3.15; also elsewhere on the board
1.1000BASET_TR0_N: J3.10; also elsewhere on the board
1.1000BASET_TR0_P: J3.12; also elsewhere on the board
1.1000BASET_TR1_N: J3.6; also elsewhere on the board
1.1000BASET_TR1_P: J3.4; also elsewhere on the board
1.1000BASET_TR2_N: J3.9; also elsewhere on the board
1.1000BASET_TR2_P: J3.11; also elsewhere on the board
1.1000BASET_TR3_N: J3.5; also elsewhere on the board
1.1000BASET_TR3_P: J3.3; also elsewhere on the board
1.AUDIO_ACLKX: J3.49; also elsewhere on the board
1.AUDIO_AXR0: J3.25
1.AUDIO_AXR1: J3.27; also elsewhere on the board
1.AUDIO_FSX: J3.26; also elsewhere on the board
1.CAM1_C_N: J2.27; also elsewhere on the board
1.CAM1_C_P: J2.29; also elsewhere on the board
1.CAM1_D1_N: J2.15; also elsewhere on the board
1.CAM1_D1_P: J2.17; also elsewhere on the board
1.CAM1_D2_N: J2.21; also elsewhere on the board
1.CAM1_D2_P: J2.23; also elsewhere on the board
1.CAM1_D3_N: J2.33
1.CAM1_D3_P: J2.35
1.CAM1_D4_N: J2.39
1.CAM1_D4_P: J2.41
1.GPIO_CAMERA_GPIO: J3.97; also elsewhere on the board
1.PCIE_CLKREQ_GPIO: J2.2; also elsewhere on the board
1.PCIE_CLK_N: J2.12; also elsewhere on the board
1.PCIE_CLK_P: J2.10; also elsewhere on the board
1.PCIE_RX0_N: J2.18; also elsewhere on the board
1.PCIE_RX0_P: J2.16; also elsewhere on the board
1.PCIE_TX0_N: J2.24; also elsewhere on the board
1.PCIE_TX0_P: J2.22; also elsewhere on the board
1.USB_OTG_ID: J2.1, R13.1
1.VLOGIC_VLOGIC: R54.1; also elsewhere on the board
3.3V_OUT$1: J3.84, J3.86, Q4.3 (D), R52.1
3.3V_SWITCH$1: Q3.3 (D), R54.2
5.5.0V_VCC_5.0: J3.77, J3.79, J3.81, J3.83, J3.85, J3.87; also elsewhere on the board
!EXTRST$1: J3.100, Q1.1 (G), R55.2
!RPIBOOT$1: J3.93; also elsewhere on the board
CORAL_D_N: J2.5; also elsewhere on the board
CORAL_D_P: J2.3; also elsewhere on the board
DS_LOAD$1: Q3.2 (S), Q4.2 (S)
DS_LOAD_1V8$1: Q7.2 (S), Q8.2 (S)
EEPROM_!WP: J3.20
ETH_SYNC_IN: J3.16
ETH_SYNC_OUT: J3.18
GLOBAL_EN: J3.99
GND: J2.7, J2.8, J2.13, J2.14, J2.19, J2.20, J2.25, J2.26, J2.31, J2.32, J2.37, J2.38, J2.44, J2.50, J2.55, J2.56, J2.61, J2.62, J2.67, J2.68, J2.73, J2.74, J2.79, J2.80, J2.85, J2.86, J2.91, J2.92, J2.97, J2.98, J3.1, J3.2, J3.7, J3.8, J3.13, J3.14, J3.22, J3.23, J3.32, J3.33, J3.42, J3.43, J3.52, J3.53, J3.59, J3.60, J3.65, J3.66, J3.71, J3.74, J3.98, MP1.1, MP2.1, MP3.1, MP4.1, Q1.2 (S), R13.2, R55.1; also elsewhere on the board
GPIO_VREF$1: J3.78, R52.2, R53.2; also elsewhere on the board
ID_SC$1: J3.35; also elsewhere on the board
ID_SD$1: J3.36; also elsewhere on the board
LOAD_GATE$1: Q1.3 (D), Q3.1 (G), Q4.1 (G), Q7.1 (G), Q8.1 (G)
PCIE_!RST: J2.9
PI_!LED_ACT: J3.21
PI_LED_!PWR: J3.95
RUN_PG: R40.2; also elsewhere on the board
RUN_PG$: J3.92, R40.1
SD_PWR_ON: J3.75
SD_VDD_OV: J3.73
VDAC_COMP: J2.11

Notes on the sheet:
Raspberry Pi CM4 (Flip-side)
GPIO
High Speed

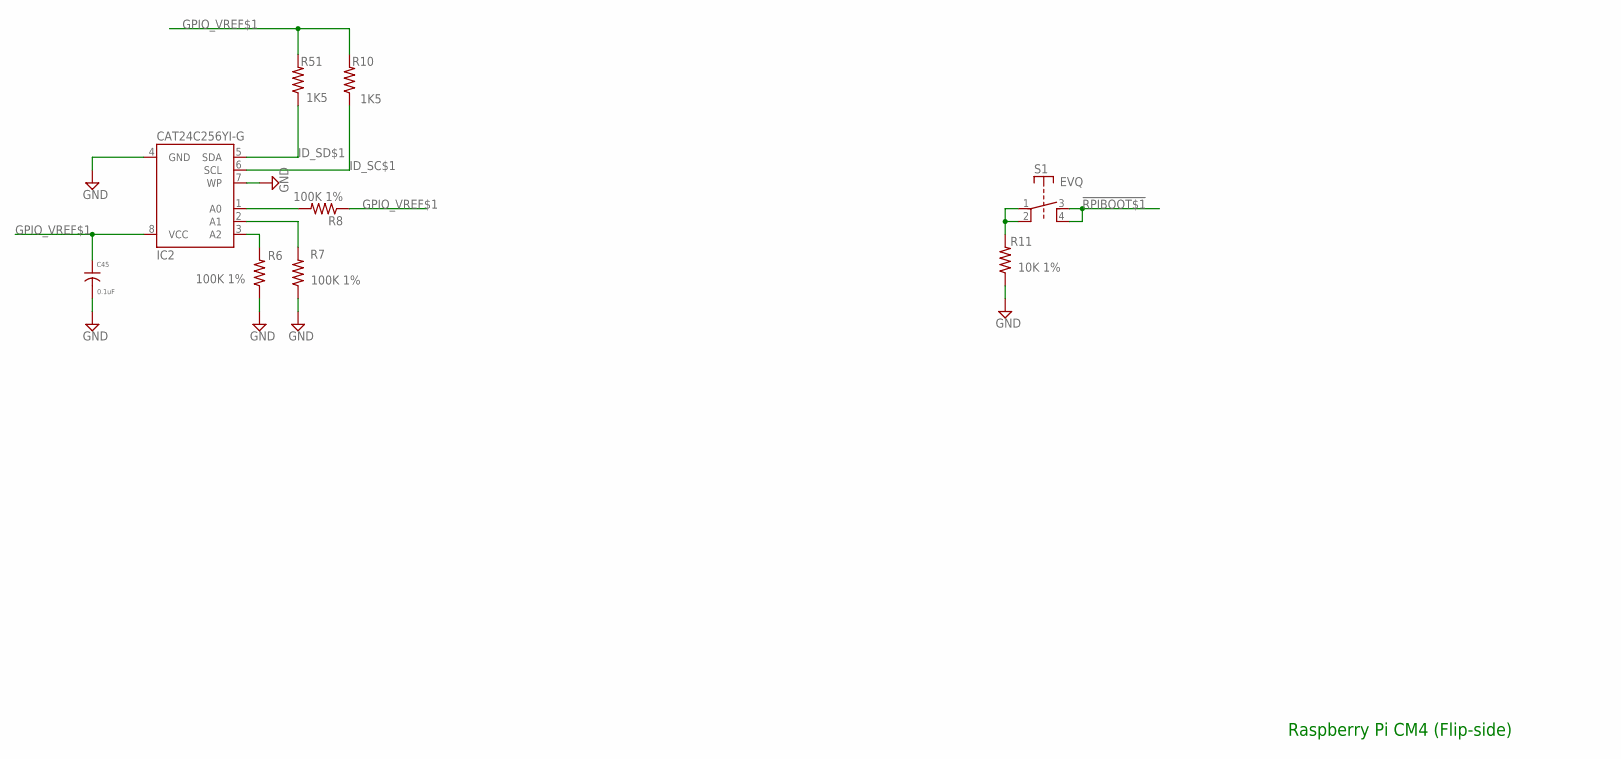
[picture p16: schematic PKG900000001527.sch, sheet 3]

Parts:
C45: 0.1uF; 0201
IC2: CAT24C256YI-G; TSSOP8
R6, R7, R8: 100K 1%; 0201
R10, R51: 1K5; 0201
R11: 10K 1%; 0201
S1: EVQ; KMT0

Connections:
!RPIBOOT$1: S1.3 (B), S1.4 (B'); also elsewhere on the board
A0$1: IC2.1 (A0), R8.2
A1$1: IC2.2 (A1), R7.2
A2$1: IC2.3 (A2), R6.2
GND: C45.2, IC2.4 (GND), IC2.7 (WP), R6.1, R7.1, R11.1; also elsewhere on the board
GPIO_VREF$1: C45.1, IC2.8 (VCC), R8.1, R10.2, R51.2; also elsewhere on the board
ID_SC$1: IC2.6 (SCL), R10.1; also elsewhere on the board
ID_SD$1: IC2.5 (SDA), R51.1; also elsewhere on the board
RPIBOOT_SWITCH$1: R11.2, S1.1 (A), S1.2 (A')

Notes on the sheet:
Raspberry Pi CM4 (Flip-side)

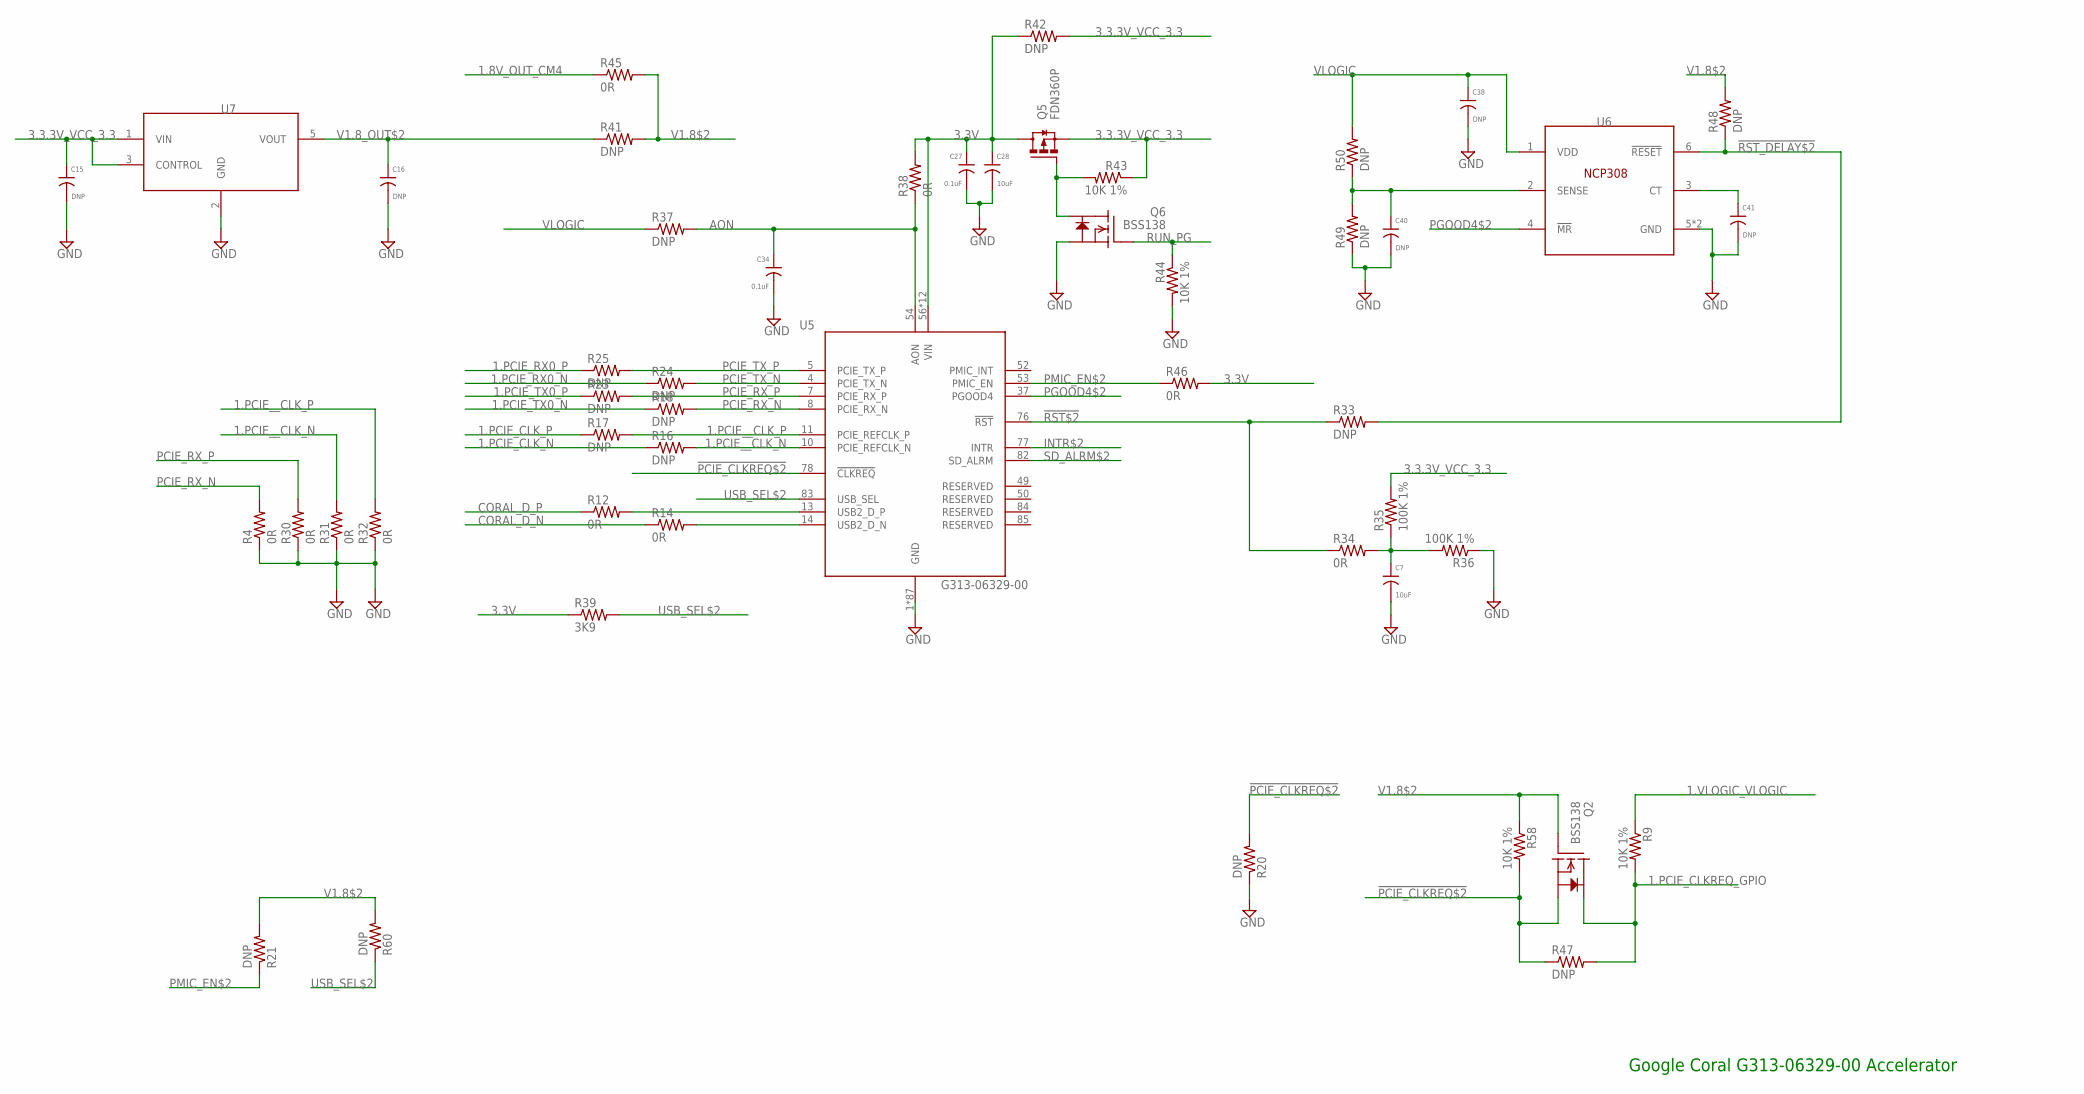
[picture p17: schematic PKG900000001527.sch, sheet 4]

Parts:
C7, C28: 10uF; 0603
C15, C38, C40, C41: DNP; 0201
C16: DNP; 0402
C27, C34: 0.1uF; 0201
Q2, Q6: BSS138; SOT23
Q5: FDN360P; SOT23
R4, R12, R14, R30, R31, R32, R34, R38, R46: 0R; 0201
R9, R43, R44, R58: 10K 1%; 0201
R16, R17, R18, R20, R21, R23, R24, R25, R33, R37, R47, R48, R49, R50, R60: DNP; 0201
R35, R36: 100K 1%; 0201
R39: 3K9; 0201
R41: DNP; 0603
R42: DNP; 0805
R45: 0R; 0603
U5: G313-06329-00
U6: DNP; WDFN6
U7: DNP; SOT-23-5

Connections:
1.8V_OUT_CM4: R45.1; also elsewhere on the board
1.PCIE_CLKREQ_GPIO: Q2.3 (D), R9.2, R47.2; also elsewhere on the board
1.PCIE_CLK_N: R16.1; also elsewhere on the board
1.PCIE_CLK_P: R17.1; also elsewhere on the board
1.PCIE_RX0_N: R24.1; also elsewhere on the board
1.PCIE_RX0_P: R25.1; also elsewhere on the board
1.PCIE_TX0_N: R18.1; also elsewhere on the board
1.PCIE_TX0_P: R23.1; also elsewhere on the board
1.PCIE__CLK_N: R16.2, R31.2, U5.10 (PCIE_REFCLK_N)
1.PCIE__CLK_P: R17.2, R32.2, U5.11 (PCIE_REFCLK_P)
1.VLOGIC_VLOGIC: R9.1; also elsewhere on the board
3.3.3V_VCC_3.3: C15.1, Q5.2 (S), R35.2, R42.2, R43.1, U7.1 (VIN), U7.3 (CONTROL); also elsewhere on the board
3.3V: C27.1, C28.1, Q5.3 (D), R38.2, R39.1, R42.1, R46.2, U5.56 (VIN), U5.57 (VIN), U5.58 (VIN), U5.59 (VIN), U5.60 (VIN), U5.61 (VIN), U5.62 (VIN), U5.63 (VIN), U5.64 (VIN), U5.65 (VIN), U5.66 (VIN), U5.67 (VIN)
!PCIE_CLKREQ$2: Q2.2 (S), R20.2, R47.1, R58.2, U5.78 (!CLKREQ)
!RST$2: R33.1, R34.1, U5.76 (!RST)
!RST_DELAY$2: R33.2, R48.1, U6.6 (!RESET)
AON: C34.1, R37.2, R38.1, U5.54 (AON)
CORAL_D_N: R14.1; also elsewhere on the board
CORAL_D_P: R12.1; also elsewhere on the board
CORAL_D__N: R14.2, U5.14 (USB2_D_N)
CORAL_D__P: R12.2, U5.13 (USB2_D_P)
CT1$2: C41.1, U6.3 (CT)
FET_ENABLE: Q5.1 (G), Q6.3 (D), R43.2
GND: C7.2, C15.2, C16.2, C27.2, C28.2, C34.2, C38.2, C40.2, C41.2, Q6.2 (S), R4.1, R20.1, R30.1, R31.1, R32.1, R36.1, R44.2, R49.1, U5.1 (GND), U5.2 (GND), U5.3 (GND), U5.6 (GND), U5.9 (GND), U5.12 (GND), U5.15 (GND), U5.16 (GND), U5.17 (GND), U5.18 (GND), U5.19 (GND), U5.20 (GND), U5.21 (GND), U5.22 (GND), U5.23 (GND), U5.24 (GND), U5.25 (GND), U5.26 (GND), U5.27 (GND), U5.28 (GND), U5.29 (GND), U5.30 (GND), U5.31 (GND), U5.32 (GND), U5.33 (GND), U5.34 (GND), U5.35 (GND), U5.36 (GND), U5.38 (GND), U5.39 (GND), U5.40 (GND), U5.41 (GND), U5.42 (GND), U5.43 (GND), U5.44 (GND), U5.45 (GND), U5.46 (GND), U5.47 (GND), U5.48 (GND), U5.51 (GND), U5.55 (GND), U5.68 (GND), U5.69 (GND), U5.70 (GND), U5.71 (GND), U5.72 (GND), U5.73 (GND), U5.74 (GND), U5.75 (GND), U5.79 (GND), U5.80 (GND), U5.81 (GND), U5.86 (GND), U5.87 (GND), U5.88 (GND), U5.89 (GND), U5.90 (GND), U5.91 (GND), U5.92 (GND), U5.93 (GND), U5.94 (GND), U5.95 (GND), U5.96 (GND), U5.97 (GND), U5.98 (GND), U5.99 (GND), U5.100 (GND), U5.101 (GND), U5.102 (GND), U5.103 (GND), U5.104 (GND), U5.105 (GND), U5.106 (GND), U5.107 (GND), U5.108 (GND), U5.109 (GND), U5.110 (GND), U5.111 (GND), U5.112 (GND), U5.113 (GND), U5.114 (GND), U5.115 (GND), U5.116 (GND), U5.117 (GND), U5.118 (GND), U5.119 (GND), U5.120 (GND), U6.5 (GND), U6.EPAD (GND), U7.2 (GND); also elsewhere on the board
INTR$2: U5.77 (INTR)
PCIE_RX_N: R4.2, R18.2, U5.8 (PCIE_RX_N)
PCIE_RX_P: R23.2, R30.2, U5.7 (PCIE_RX_P)
PCIE_TX_N: R24.2, U5.4 (PCIE_TX_N)
PCIE_TX_P: R25.2, U5.5 (PCIE_TX_P)
PGOOD4$2: U5.37 (PGOOD4), U6.4 (!MR)
PMIC_EN$2: R21.1, R46.1, U5.53 (PMIC_EN)
RST_RC$: C7.1, R34.2, R35.1, R36.2
RUN_PG: Q6.1 (G), R44.1; also elsewhere on the board
SD_ALRM$2: U5.82 (SD_ALRM)
SENSE$2: C40.1, R49.2, R50.1, U6.2 (SENSE)
USB_SEL$2: R39.2, R60.1, U5.83 (USB_SEL)
V1.8$2: Q2.1 (G), R21.2, R41.2, R45.2, R48.2, R58.1, R60.2
V1.8_OUT$2: C16.1, R41.1, U7.5 (VOUT)
VLOGIC: C38.1, R37.1, R50.2, U6.1 (VDD)

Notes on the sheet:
Google Coral G313-06329-00 Accelerator

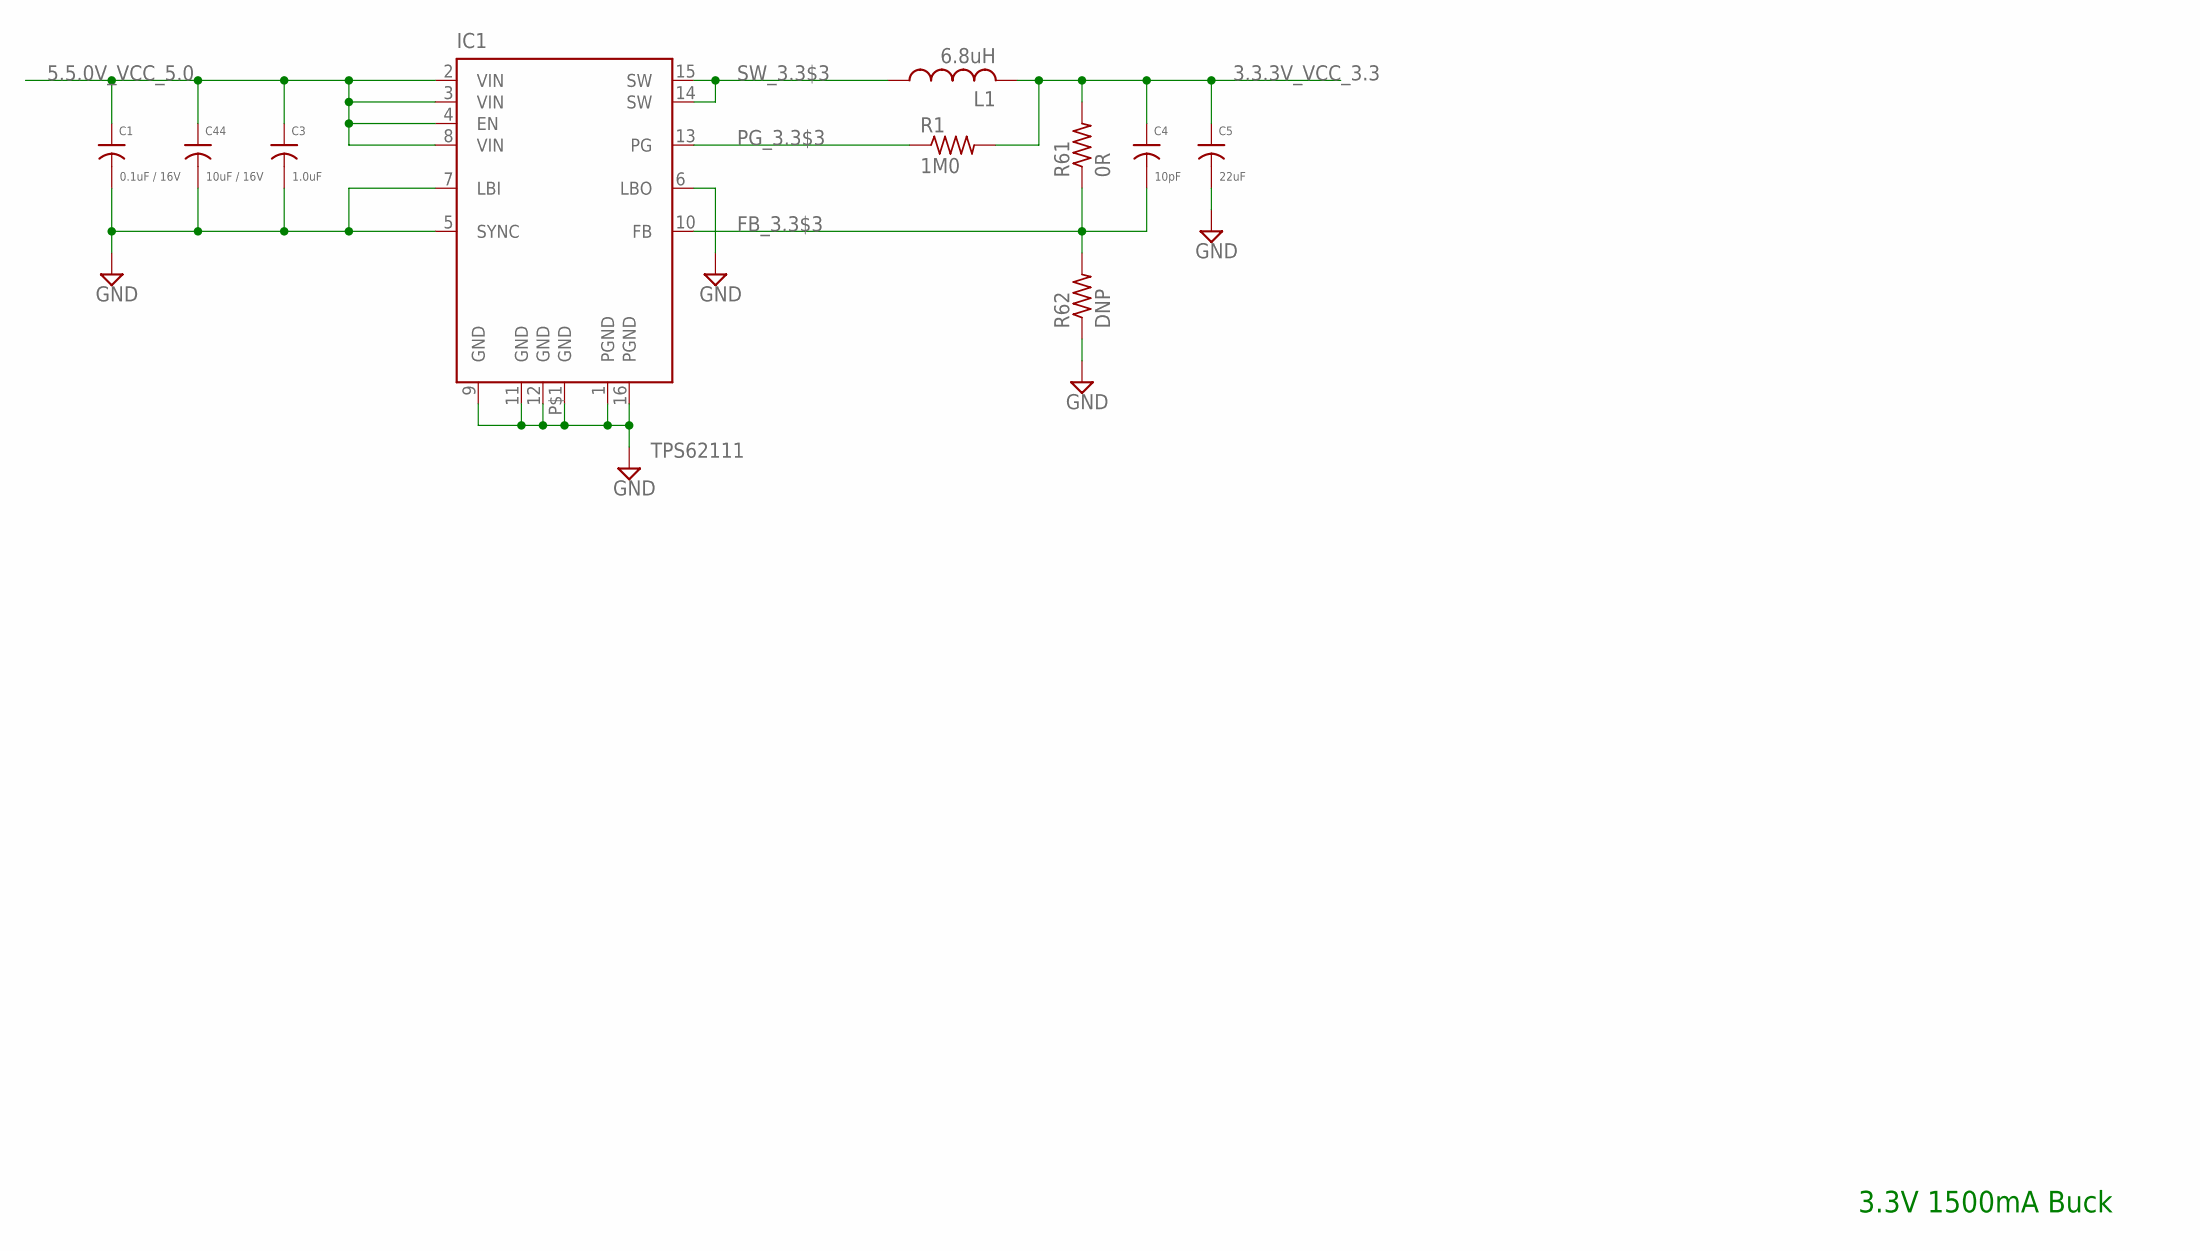
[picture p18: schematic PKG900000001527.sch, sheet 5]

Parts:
C1: 0.1uF / 16V; 0402
C3: 1.0uF; 0402
C4: 10pF; 0201
C5: 22uF; 0805
C44: 10uF / 16V; 0805
IC1: TPS62111; PQFP16
L1: 6.8uH; 1515
R1: 1M0; 0201
R61: 0R; 0402
R62: DNP; 0402

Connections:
3.3.3V_VCC_3.3: C4.1, C5.1, L1.2, R1.2, R61.2; also elsewhere on the board
5.5.0V_VCC_5.0: C1.1, C3.1, C44.1, IC1.2 (VIN), IC1.3 (VIN), IC1.4 (EN), IC1.8 (VIN); also elsewhere on the board
FB_3.3$3: C4.2, IC1.10 (FB), R61.1, R62.2
GND: C1.2, C3.2, C5.2, C44.2, IC1.1 (PGND), IC1.5 (SYNC), IC1.6 (LBO), IC1.7 (LBI), IC1.9 (GND), IC1.11 (GND), IC1.12 (GND), IC1.16 (PGND), IC1.P$1 (GND), R62.1; also elsewhere on the board
PG_3.3$3: IC1.13 (PG), R1.1
SW_3.3$3: IC1.14 (SW), IC1.15 (SW), L1.1

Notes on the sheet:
3.3V 1500mA Buck

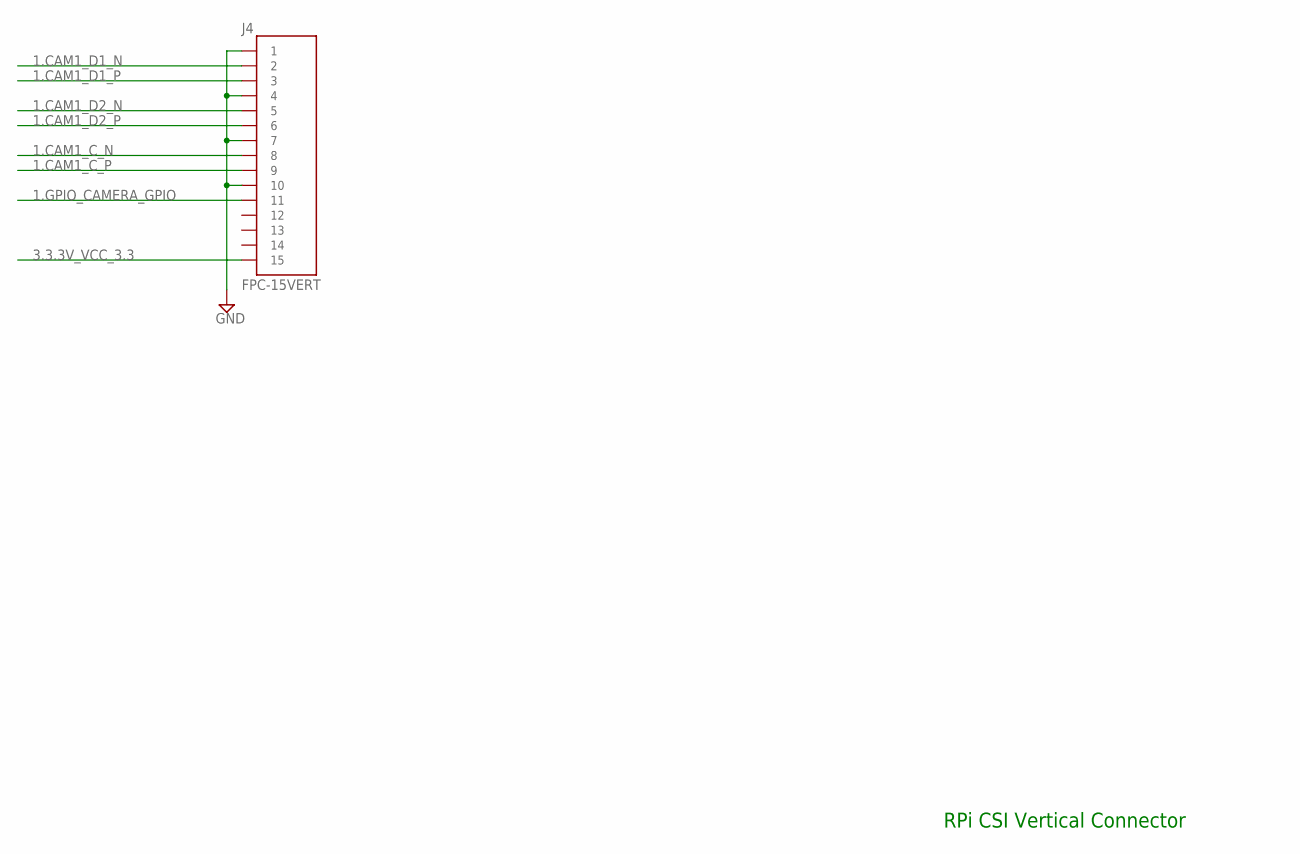
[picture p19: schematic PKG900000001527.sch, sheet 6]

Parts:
J4: FPC-15VERT; 1-1734248-5

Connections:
1.CAM1_C_N: J4.1_8 (8); also elsewhere on the board
1.CAM1_C_P: J4.1_9 (9); also elsewhere on the board
1.CAM1_D1_N: J4.1_2 (2); also elsewhere on the board
1.CAM1_D1_P: J4.1_3 (3); also elsewhere on the board
1.CAM1_D2_N: J4.1_5 (5); also elsewhere on the board
1.CAM1_D2_P: J4.1_6 (6); also elsewhere on the board
1.GPIO_CAMERA_GPIO: J4.1_11 (11); also elsewhere on the board
3.3.3V_VCC_3.3: J4.1_15 (15); also elsewhere on the board
GND: J4.1_1 (1), J4.1_4 (4), J4.1_7 (7), J4.1_10 (10); also elsewhere on the board

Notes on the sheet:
RPi CSI Vertical Connector

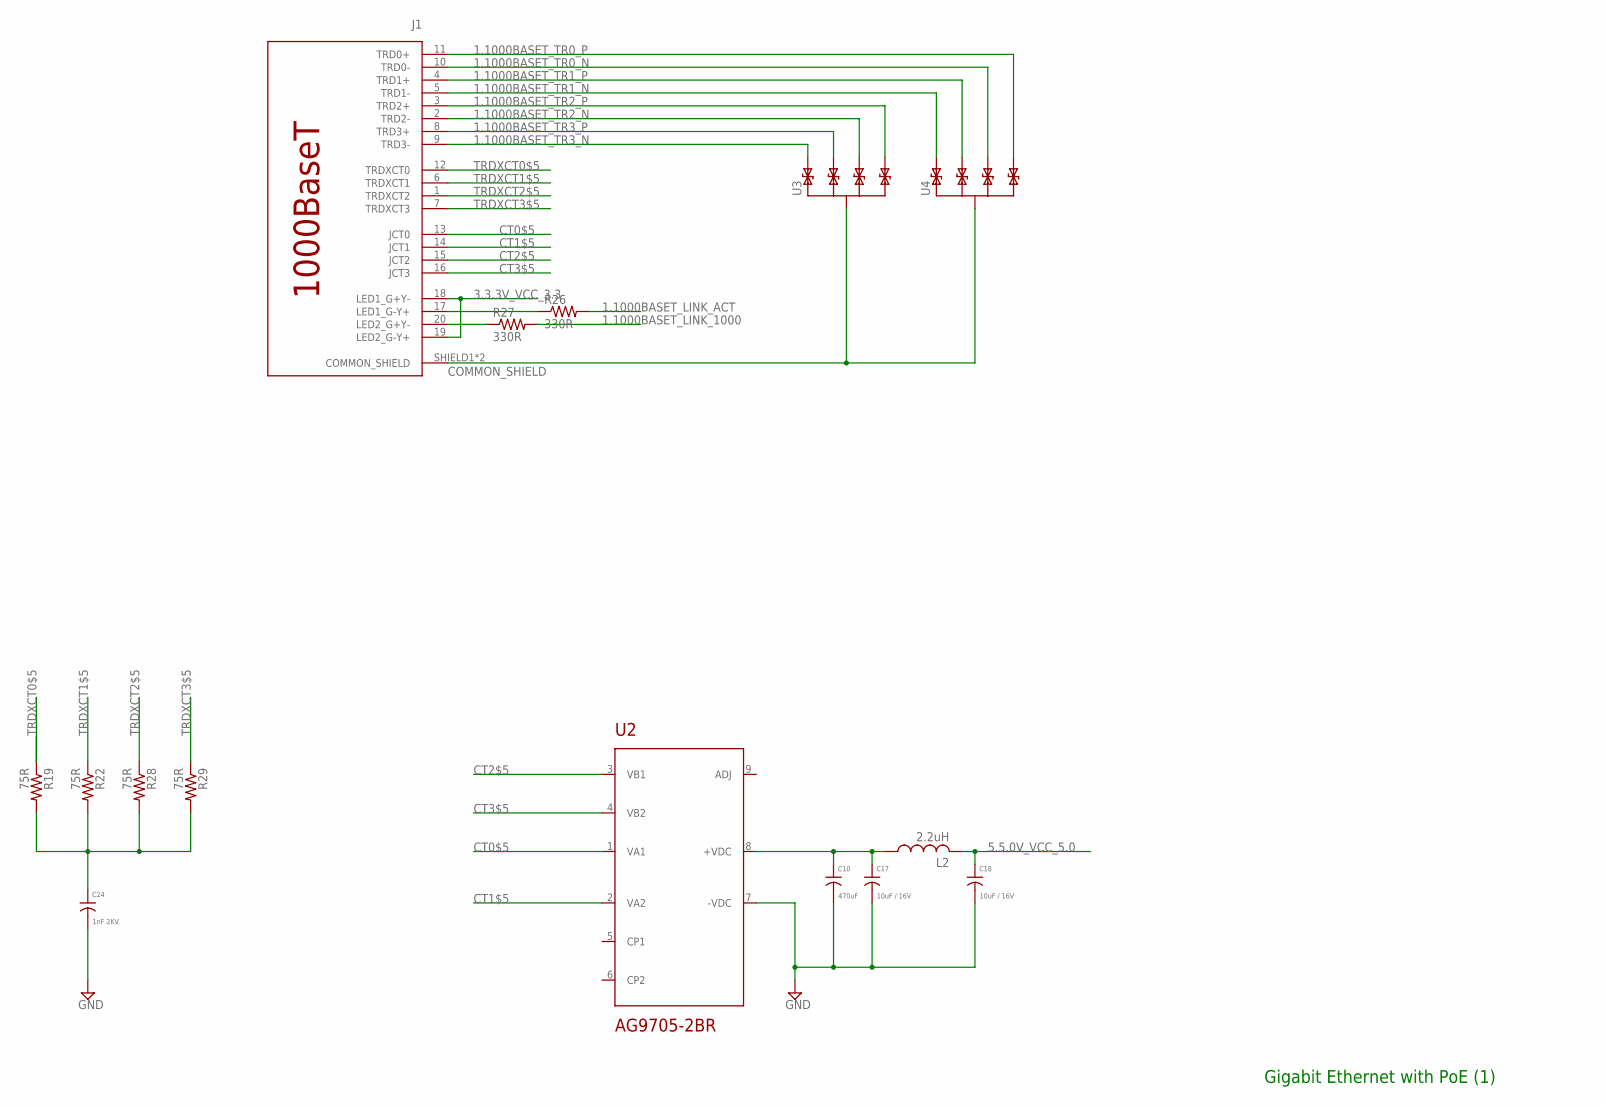
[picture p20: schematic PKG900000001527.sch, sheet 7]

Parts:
C10: 470uF; PANASONIC_F
C17, C18: 10uF / 16V; 0805
C24: 1nF 2KV; 1206
J1: 1000BASET_POE; 7499511440
L2: 2.2uH; 1515
R19, R22, R28, R29: 75R; 0402
R26, R27: 330R; 0402
U2: AG9705-2BR; AG9700
U3, U4: TPD4E02B0410-USON; UFDFN-10

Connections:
1.1000BASET_LINK_1000: R27.2; also elsewhere on the board
1.1000BASET_LINK_ACT: R26.2; also elsewhere on the board
1.1000BASET_TR0_N: J1.10 (TRD0-), U4.4 (P3), U4.7 (P3); also elsewhere on the board
1.1000BASET_TR0_P: J1.11 (TRD0+), U4.5 (P4), U4.6 (P4); also elsewhere on the board
1.1000BASET_TR1_N: J1.5 (TRD1-), U4.1, U4.10 (P1); also elsewhere on the board
1.1000BASET_TR1_P: J1.4 (TRD1+), U4.2, U4.9 (P2); also elsewhere on the board
1.1000BASET_TR2_N: J1.2 (TRD2-), U3.4 (P3), U3.7 (P3); also elsewhere on the board
1.1000BASET_TR2_P: J1.3 (TRD2+), U3.5 (P4), U3.6 (P4); also elsewhere on the board
1.1000BASET_TR3_N: J1.9 (TRD3-), U3.1, U3.10 (P1); also elsewhere on the board
1.1000BASET_TR3_P: J1.8 (TRD3+), U3.2, U3.9 (P2); also elsewhere on the board
3.3.3V_VCC_3.3: J1.18 (LED1_G+Y-), J1.19 (LED2_G-Y+); also elsewhere on the board
5.5.0V_VCC_5.0: C18.1, L2.2; also elsewhere on the board
COMMON_SHIELD: J1.SHIELD1 (COMMON_SHIELD), J1.SHIELD2 (COMMON_SHIELD), U3.3 (SHIELD), U3.8 (SHIELD), U4.3 (SHIELD), U4.8 (SHIELD)
CT0$5: J1.13 (JCT0), U2.1 (VA1)
CT1$5: J1.14 (JCT1), U2.2 (VA2)
CT2$5: J1.15 (JCT2), U2.3 (VB1)
CT3$5: J1.16 (JCT3), U2.4 (VB2)
GND: C10.- (2), C17.2, C18.2, C24.2, U2.7 (-VDC); also elsewhere on the board
MFA0_R$5: J1.20 (LED2_G+Y-), R27.1
MFA1_R$5: J1.17 (LED1_G-Y+), R26.1
TRDXCT0$5: J1.12 (TRDXCT0), R19.1
TRDXCT1$5: J1.6 (TRDXCT1), R22.1
TRDXCT2$5: J1.1 (TRDXCT2), R28.1
TRDXCT3$5: J1.7 (TRDXCT3), R29.1
TRDXCT_COMMON$5: C24.1, R19.2, R22.2, R28.2, R29.2
V3.3_UNFILT$5: C10.+ (1), C17.1, L2.1, U2.8 (+VDC)

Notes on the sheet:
Gigabit Ethernet with PoE (1)

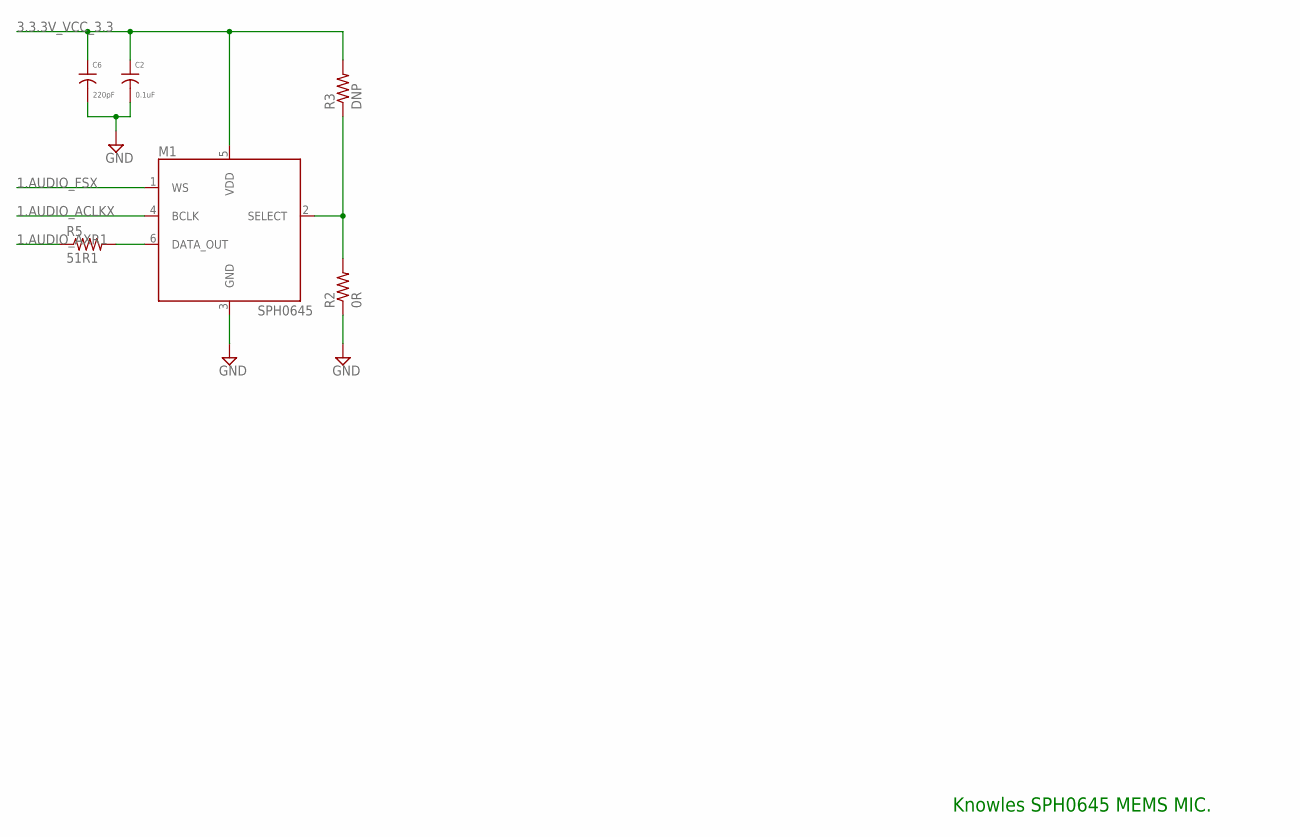
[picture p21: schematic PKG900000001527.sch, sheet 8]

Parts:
C2: 0.1uF; 0201
C6: 220pF; 0201
M1: SPH0645
R2: 0R; 0201
R3: DNP; 0201
R5: 51R1; 0402

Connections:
1.AUDIO_ACLKX: M1.4 (BCLK); also elsewhere on the board
1.AUDIO_AXR1: R5.1; also elsewhere on the board
1.AUDIO_FSX: M1.1 (WS); also elsewhere on the board
3.3.3V_VCC_3.3: C2.1, C6.1, M1.5 (VDD), R3.2; also elsewhere on the board
GND: C2.2, C6.2, M1.3 (GND), R2.1; also elsewhere on the board
SDI$7: M1.6 (DATA_OUT), R5.2
SELECT$7: M1.2 (SELECT), R2.2, R3.1

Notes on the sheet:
Knowles SPH0645 MEMS MIC.

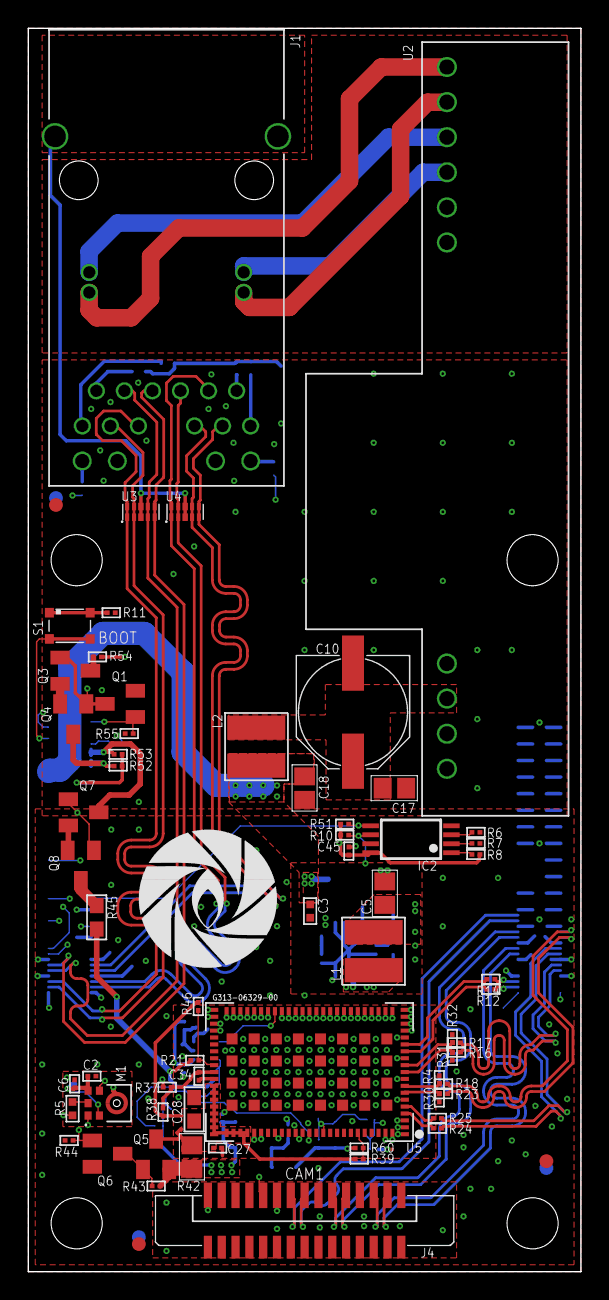
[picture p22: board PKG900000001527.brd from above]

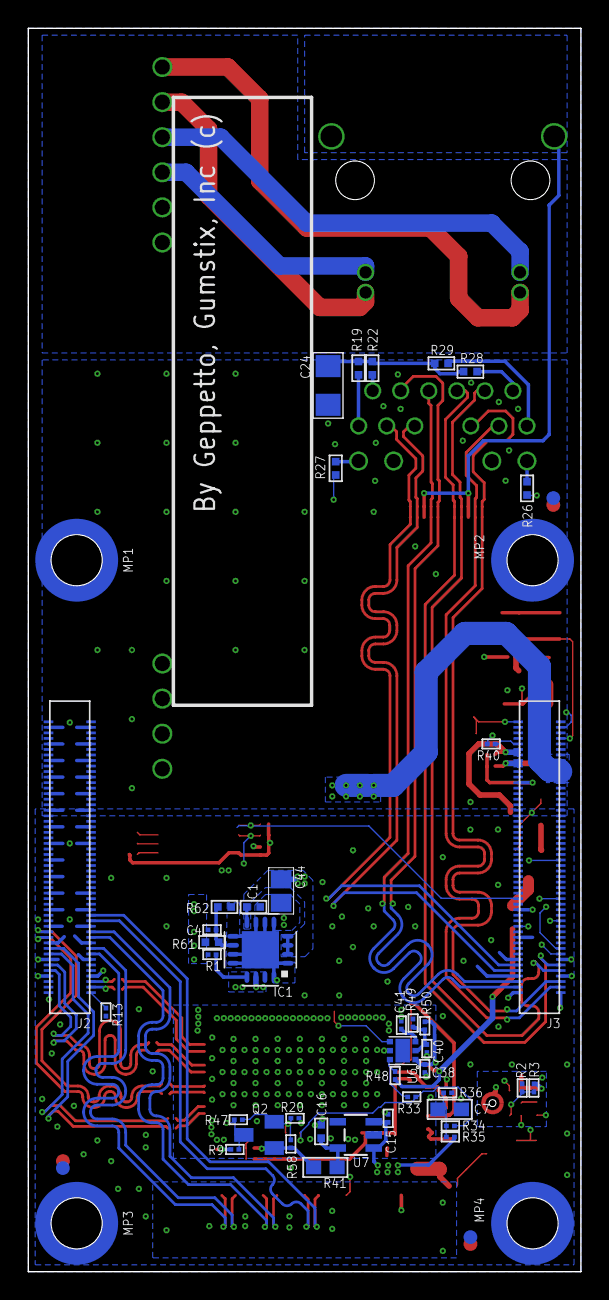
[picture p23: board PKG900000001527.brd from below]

Board: 6 copper layers, 40.0 x 90.0 mm, 115 parts (49 on the bottom side), 93 nets.

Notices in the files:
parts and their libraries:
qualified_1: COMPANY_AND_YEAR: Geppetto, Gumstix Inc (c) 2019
